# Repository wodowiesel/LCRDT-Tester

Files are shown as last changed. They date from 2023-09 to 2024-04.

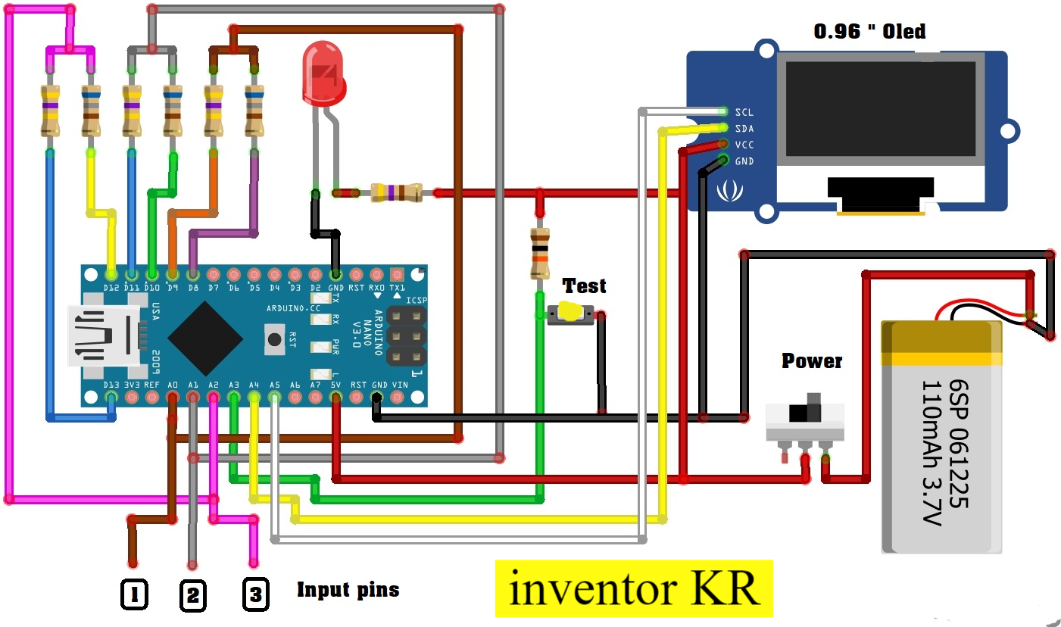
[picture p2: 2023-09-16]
docs/electronic-component-tester-nano.png

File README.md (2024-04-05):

# LCRDT-Tester

The Tester is a tool for identification of the electronic components and its values based on Arduino Nano v3 with internal reference incl. pcb schematics & code.

PCB

Compatibility list:

- Inductors
- Capacitors
- Resistors
- Diodes
- Transistors

- Vloss
- ESR
- Type (PNP/NPN/FET/MOS)
- hFE B

## DISCLAIMERS

**This is still "work-in-progress (WIP)" so I do NOT take any kind of responsibility for damages/data losses!**

**You can use this at your own risk without guarantees and put device on non conductive surface or enclosure!**

If you like the new design yo are free to share it!

Have fun :)

## HARDWARE

- 1x Arduino Nano v3 (or Uno for old versions) + USB-Cable
- 1x Custom PCB for Arduino Nano v3 by WodoWiesel
- 3x 10 kOhm Resistors
- 3x 330 Ohm Resistors
- 1x 100 nF capacitor (or without, just bridge it)
- 1x 4-pin display for +3.3V (0.96" OLED)
- 2x Push-Button (reset & start)
- 1x 3-Pin Male Pin Header (for component testing)
- 1x 4-Pin Male Pin Header (for display)

- 1x Soldering iron
- Solder + flux + IPA

## SOFTWARE

Download my adapted [code](/code-aduino/LCRDT-Tester-WodoWiesel.ino) and configure your setup and load it via Arduino IDE.

## HOW TO USE

1. configure code adapted to your setup regarding used parts and display type

2. upload code to your arduino

3. solder the new pcb

4. put component of choice in the testing headers and read values

## CREDITS

:copyright: 10/10/2023 WodoWiesel

Github (https://github.com/wodowiesel/)

Twitch (https://www.twitch.com/wodowiesel/)

Instagram (https://www.instagram.com/wodowiesel/)

YT (https://www.youtube.com/@wodowiesel/)

E-Mail (wodowiesel@quantentunnel.de)

The new design was checked by the electrical engineer theBrutzler

(https://github.com/theBrutzler/ & https://www.twitch.com/theBrutzler/)

The new optimized PCB was designed with free KiCAD software (https://www.kicad.org/)

:heavy_exclamation_mark: The PCB should be produced at a manufacturer

(like PCBWay or similar) with the RoHS lead-free option for environmental protection.

Originals:

Proekty (https://arduino.ru/forum/proekty/transistor-tester-arduino/)

Vlad (https://github.com/vlad-gheorghe/ardutester/)

Code: Karl-Heinz Kubbeler (version 1.08k, 2013 / 1.10, 2014)

engl. Journal [PDF](/docs/ttester_eng108k.pdf)

## LICENSES

- Hardware

CERN Open Hardware License Version 2 - Weakly Reciprocal

Short identifier CERN-OHL-W-2.0

[LICENSE Source](https://spdx.org/licenses/CERN-OHL-W-2.0.html)

- Software

This work is licensed under a Creative Commons Attribution-NonCommercial 3.0 Unported License.

[CCANC](http://creativecommons.org/licenses/by-nc/3.0/)

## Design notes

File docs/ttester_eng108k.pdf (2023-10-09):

# TransistorTester with AVR microcontroller and a little more Version 1.08k

### Karl-Heinz K¨ubbeler

kh kuebbeler@web.de

### September 25, 2013

# Contents

1 Features | 4
2 Hardware | 7
3 Instructions for use | 15
4 Configuring the TransistorTester | 19
5 Description of the measurement procedures | 24

5.5 Selftest Function | 66
5.5.1 | Some Results of the Selftest Function | 70
6 Known errors and unsolved problems | 73
7 Special Software Parts | 74
8 To Do List and new ideas | 75

## Preface

### Basically Motive

Every hobbyist knows the following problem: You disassemle a Transistor out of a printed board or you get one out of a collection box. If you find out the identification number and you already have a data sheet or you can get the documents about this part, everything is well. But if you don’t find any documents, you have no idea, what kind of part this can be. With conventional approach of measurement it is difficult and time-consuming to find out the type of the part and parameters. It could be a NPN, PNP, N- or P-Channel-Mosfet etc. It was the idea of Markus F. to hand over the work to a AVR microcontroller.

### As my work has started

My work with the software of the TransistorTester of Markus F. [1] has started, because I had problems with my programmer. I had bought a printed board and components, but I could not program the EEprom of the ATmega8 with the Windows driver without error messages. Therefore I took the software of Markus F. and changed all the accesses from the EEprom memory to flash memory accesses. By analysing the software in order to save memory at other places of program, I had the idea, to change the result of the ReadADC function from ADC units to millivolt (mV) units. The mV resolution is needed for any output of voltage values. If ReadADC returns directly the mV resolution, I can save the conversion for each output value. This mV resolution can be get, if you first accumulate the results of 22 ADC readings. The sum must be multiplied with two and divided by nine. Then we have a maximum value of 1023·22·2
9 = 5001, which matches perfect to the wanted mV resolution of measured voltage values. So I additionally had the hope, that the enhancement of ADC resolution by oversampling could help to improve the voltage reading of the ADC, as described in AVR121 [5]. The original version ReadADC has accumulated the result of 20 ADC measurements and divides afterwards by 20, so the result is equal to original ADC resolution. By this way never a enhancement of ADC resolution can take place. So I had to do little work to change the ReadADC, but this forced analysing the whole program and change of all “if-statements” in the program, where voltage values are queried. But this was only the beginning of my work!

More and more ideas to make measurement faster and more accurate has been implemented. Additionally the range of resistor and capacity measurements are extended. The output format for LCD-Display was changed, so symbols are taken for diodes, resistors and capacitors instead of text. For further details take a look to the actual feature list chapter 1. Planned work and new ideas are accumulated in the To Do List in chapter 8. By the way, now I can program the EEprom of the ATmega with Linux operating system without errors.
At this place I would like to thank the originator and software author Markus Frejek, who has enabled the continuation with his initial work. In addition I would like to say thanks to the authors of numerous input to the discussion forum, which have assist me, to find new tasks, weak points and errors. Next I would like to thank Markus Reschke, who give me the permission, to publish his cheerful software versions at the SVN server. Furthermore some ideas and software part of Markus
R. was integrated in my own software version, again thank you very much. I have to thank also Asco B., who has developed a new printed board, to enable the reproductions for other hobbyists. Another thank I would like to send to Dirk W. , who has handled the omnibus order for this printed board. Never I had time anough to handle these things concurrently with my software developement, at no time the state of further developement of software would have the same level. Thanks for the many suggestions to improve the tester to the members of the local chapter of the ”Deutscher Amateur Radio Club (DARC)” in Lennestadt.

# Chapter 1

# Features

1. Operates with ATmega8, ATmega168 or ATmega328 microcontrollers.
2. Displaying the results to a 2x16 character LCD-Display.
3. One key operation with automatic power shutdown.
4. Battery operation is possible since shutdown current is only about 20nA.
5. Low cost version is feasible without crystal and auto power off. With software version 1.05k the sleep modus of the Atmega168 or ATmega328 is used to reduce current if no measurement is required.
6. Automatic detection of NPN and PNP bipolar transistors, N- and P-Channel MOSFETs, JFETs, diodes, double diodes, Thyristors and Triacs.
7. Automatic detection of pin layout of the detected part.
8. Measuring of current amplification factor and Base-Emitter threshold voltage of bipolar transistors.
9. Darlington transistors can be identified by the threshold voltage and high current amplification factor.
10. Detection of the protection diode of bipolar transistors and MOSFETs.
11. Measuring of the Gate threshold voltage and Gate capacity value of MOSFETs.
12. Up to two Resistors are measured and shown with symbols | and values with up to four
decimal digits in the right dimension. All symbols are surrounded by the probe numbers of the Tester (1-3). So Potentiometer can also be measured. If the Potentiometer is adjusted to one of its ends, the Tester cannot differ the middle pin and the end pin.
13. Resolution of resistor measurement is now up to 0.01Ω, values up to 50MΩ are detected.
14. One capacitor can be detected and measured. It is shown with symbol and value with up to four decimal digits in the right dimension. The value can be from 25pF (8MHz clock, 50pF @1MHz clock) to 100mF. The resolution can be up to 1 pF (@8MHz clock].
15. For capacitors with a capacity value above 0.18µF the Equivalent Serial Resistance (ESR) is measured with a resolution of 0.01Ω and shown with two significant decimal digits. This feature is only avaiable for ATmega with at least 16K flash memory (ATmega168 or ATmega328).

16. For capacitors with a capacity value above 5000pF the voltage loss after a load pulse can be determined. The voltage loss give a hint for the quality factor of the capacitor.
17. Up to two diodes are shown with symbol | or symbol | in correct order. Additionally
the flux voltages are shown.
18. LED is detected as diode, the flux voltage is much higher than normal. Two-in-one LEDs are also detected as two diodes.
19. Zener-Diodes can be detected, if reverse break down Voltage is below 4.5V. These are shown as two diodes, you can identify this part only by the voltages. The outer probe numbers, which surround the diode symbols, are identical in this case. You can identify the real Anode of the diode only by the one with break down (threshold) Voltage nearby 700mV!
20. If more than 3 diode type parts are detected, the number of founded diodes is shown additionally to the fail message. This can only happen, if Diodes are attached to all three probes and at least one is a Z-Diode. In this case you should only connect two probes and start measurement again, one after the other.
21. Measurement of the capacity value of a single diode in reverse direction. Bipolar Transistors can also be analysed, if you connect the Base and only one of Collector or Emitter.
22. Only one measurement is needed to find out the connections of a bridge rectifier.
23. Capacitors with value below 25pF are usually not detectet, but can be measured together with a parallel diode or a parallel capacitor with at least 25pF. In this case you must subtract the capacity value of the parallel connected part.
24. For resistors below 2100Ω also the measurement of inductance will be done, if your ATmega has at least 16K flash memory. The range will be from about 0.01mH to more than 20H, but the accuracy is not good. The measurement result is only shown with a single component connected.
25. Testing time is about two seconds, only capacity or inductance measurement can cause longer period.
26. Software can be configured to enable series of measurements before power will be shut down.
27. Build in selftest function with optional 50Hz Frequency generator to check the accuracy of clock frequency and wait calls (ATmega168 and ATmega328 only).
28. Selectable facility to calibrate the internal port resistance of port output and the zero offset of capacity measurement with the selftest (ATmega168 and ATmega328 only). A external capacitor with a value between 100nF and 20µF connected to pin 1 and pin 3 is necessary to compensate the offset voltage of the analog comparator. This can reduce measurement errors of capacitors of up to 40µF. With the same capacitor a correction voltage to the internal reference voltage is found to adjust the gain for ADC measuring with the internal reference.

Thyristors and Triacs can only be detected, if the test current is above the holding current. Some Thyristors and Triacs need as higher gate trigger current, than this Tester can deliver. The available testing current is only about 6mA! Notice that all features can only be used with microcontroller with more program memory such as ATmega168.

Attention: Allways be shure to discharge capacitors before connecting them to the Tester! The Tester may be damaged before you have switched it on. There is only a little protection at the ATmega ports.
Extra causion is required if you try to test components mounted in a circuit. In either case the equipment should be disconnected from power source and you should be shure, that no residual voltage remains in the equipment.

# Chapter 2

# Hardware

## 2.1 Circuit of the TransistorTester

The circuit of the TransistorTester in figure 2.1 is based on the circuit of Markus F. released in Abb. 1 of AVR-Transistortester report [1]. Changed or moved parts are marked with green color, optional parts are marked with red color.
Some changes are made because the electronical power switch make problems in some implemen-tations. Therefore the resistor R7 is reduced to 3.3kΩ. The capacitor C2 is reduced to 10nF and R8 is moved so that the PD6 output does not try to switch the C2 capacitor directly. Additional blocking capacitors are added and should be placed near the power connection of the Atmega and near the Voltage regulator.
Because the PD7 input and PC6 (RESET) are the only pins, where pull up resistors where needed, one extra 27kΩ resistor is added to the PD7 (pin 13) input. With this modification the software can disable all internal pull up resistors of the ATmega.
The additional crystal with its 22pF capacitors are optional added. The accuracy of a crystal has the benefit of more stable time measurement for getting the capacitor values.
New software version can use a voltage scale switch of the ADC. The speed of switching is reduced by the external capacitor C1 at the AREF (21) pin of the ATmega. To avoid slowing down the measurement speed more than necessary, the value of this capacitor should be reduced to 1nF. Removing of the capacitor C1 is also possible. For adapting the software to the actual circuit take a look to the Makefile options in the configuring chapter 4.
Some different versions of R11 / R12 resistor combinations circulates in the internet. I have adapted my software to the original of Markus F. [1] with 10kΩ and 3.3kΩ.
The additional 2.5V precision voltage reference connected at pin PC4 (ADC4) can be used to check and calibrate the VCC voltage, but is not required. You can use a LM4040-AIZ2.5 (0.1%), a LT1004CZ-2.5 (0.8%) or a LM336-Z2.5 (0.8%) as voltage reference. A optional ISP connector has been added to easier load new software versions to the tester.

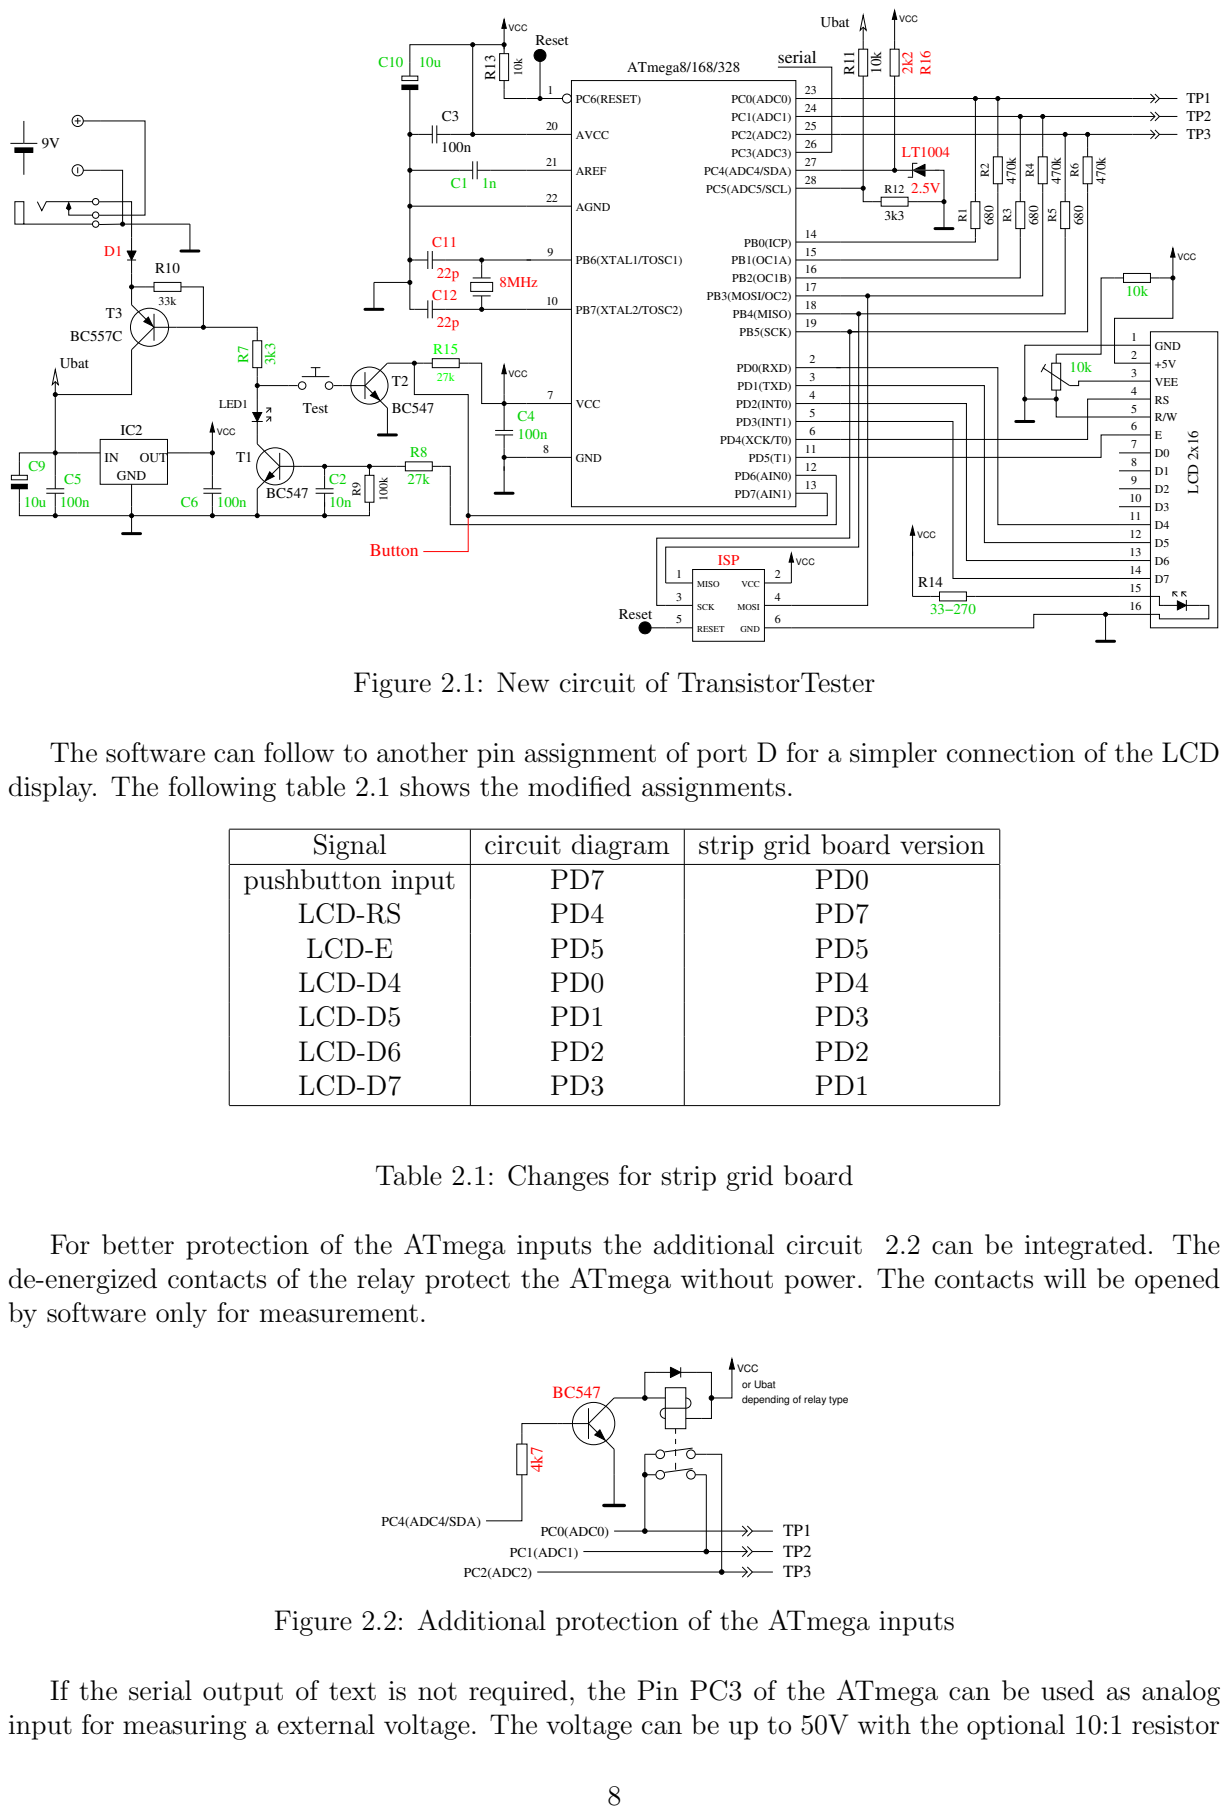
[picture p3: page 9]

Figure 2.1: New circuit of TransistorTester

The software can follow to another pin assignment of port D for a simpler connection of the LCD
display. The following table 2.1 shows the modified assignments.

Signal | circuit diagram | strip grid board version
pushbutton input LCD-RS LCD-E LCD-D4 LCD-D5 LCD-D6 LCD-D7 | PD7 PD4 PD5 PD0 PD1 PD2 PD3 | PD0 PD7 PD5 PD4 PD3 PD2 PD1

Table 2.1: Changes for strip grid board

For better protection of the ATmega inputs the additional circuit 2.2 can be integrated. The
de-energized contacts of the relay protect the ATmega without power. The contacts will be opened
by software only for measurement.

VCC Figure 2.2: Additional protection of the ATmega inputs

or Ubat
depending of relay type

If the serial output of text is not required, the Pin PC3 of the ATmega can be used as analog
input for measuring a external voltage. The voltage can be up to 50V with the optional 10:1 resistor

divider and can be used for measuring the breakdown voltage of a zener diode. A current limiting power supply with up to 50V can be switched on with low signal at PD7 pin of the ATmega to deliver current for testing the break down voltage of a zener diode. Figure 2.3 shows a suggestion for this expansion. The tester shows the external voltage as long as you hold the key pressed. About 40mA more battery current is used by this expansion during key pressing.

Vin+

Vin−

Com DC−DC Conv.

Vout+15

Vout−15

R18

180k

R17

20k

10n

serial / PC3

External
Voltage

1uF

33uH

L1

C13

Uext
10k

TMA0515D

T4
Uext

Button

R19

Ubat

C15

100n

Can be placed on Tester board! Should be placed separate!

IN OUT

IC3

GND

MCP1702

IRFU9024

C17

C16

50u 100n
C14

Figure 2.3: Expansion for measuring of break down voltage of Zener diodes

## 2.2 Hints for building the TransistorTester

Every LCD-display with at least 2x16 character and a HD44780 compatible controller can be used with the TransistorTester. You should respect the current needed for illumination, some LCD need lower current than others. I had tried OLED type displays, but this type cause interference with measurements of the ATmega and are not recommended. Also loading of special characters for displaying the resistor symbol has caused problems with the OLED.
The resistors R1 to R6 are critical for measurements and this 680Ω and 470kΩ resistors should be measurement type resistors (tolerance of 0.1%) to get the full accuracy. You should use a precision socket for the ATmega microcontroller to enable the replacement of the microcontroller. The microcontroller ATmega8, ATmega168 and ATmega328 can be used. Recommended is a ATmega168 or ATmega328, if you wish to use all features.
Anyway you should assemble all parts to printed board without the microcontroller. A up-to-date low voltage drop regulator like MCP1702-5002 is recommended as IC2, because it need only 2µA of standby current and can still deliver 5V, if your input voltage is only 5.4V. But this part is not pin compatible to well known 78L05 with TO92 body!
After checking, that all needed parts are at the correct place, you should first connect the battery or power supply to the printed board without LCD-display and microcontroller. You should check the voltage at the power pins of the microcontroller and LCD-display terminal during the Test key is pressed. The voltage should disappear, if you release the Test key. If the voltage had correct polarity and value, you should disconnect the power and assemble the microcontroller with correct alignment. Be careful and make shure, that all pins of the microcontroller are in the socket holes. Now you can also connect the LCD. Check if power pins of the LCD has the right connection to GND and VCC of your board.
If you are shure that everything is all right, reconnect the power. If you have already programmed the ATmega, you can press the Test button. By pressing the Test key, the background light of the LCD should switch on. If you release the Test button, the LED should illuminate weak. Notice, that the software for the microcontroller must be compiled for the correct processor type. A program for the ATmega8 does not run on a ATmega168!

2.3 Changeover for tester versions designed by Markus F.

Voltage control If the problem exist, the tester will shut down immediately with every switch on. With imy suggested setting of the fuses (Makefile) the voltage control of the different ATmega versions is switched to 4V (brown out level). This may be the reason why the tester makes trouble with the power on sequence. The Pin PD6 tries to switch the 100nF capacitor C2 to VCC level causing a voltage breakdown of the VCC voltage (5V). The capacitor C2 can be reduced to <10nF without problems. If possible, the direct connection of PD6 should be replaced by a resistor >220Ω.

Improvement of power on circuit Often this problem is the reason, if the tester starts with the button hold pressed, but switch off directly by releasing. The problem is enforced by a high current background light for the LCD. The resistor R7 to the base of the PNP transistor T3 was optimized with the value 27kΩ too much to save power consuming. To improve the switching with lower battery voltage or lower current amplification factor of the PNP transistor T3, you should reduce the resistance to 3.3kΩ.

Additional pull-up resistor at PD7 The missing pull-up resistor results to a switch off of the tester with the message ”Timeout” after a short display time. The software is configured with the option PULLUP DISABLE, that all internal pull-up resistors are switched off. For that reason the voltage of pin PD7 is not definded, if the level is not switched by the push button or transistor T2 to GND. One external pull-up resistor of 27kΩ to VCC avoid this error.

Capacitor C1 at the AREF pin Many designs use a 100nF capacitor at the AREF pin, like the design of Markus F. too. As long as the reference voltage of the ADC is never changed, this is a good solution. The software of the TransistorTester for the ATmega168/328 uses a automatic selection of the internal 1.1 V reference voltage of the ADC, if the input voltage is below 1V. With this solution a better resolution of the ADC can be reached for little input voltages. Unfortunately the switching from 5V to 1.1V reference is very slowly. A additional wait time of 10ms must be respected for this reason. With changing the capacity value to 1nF this wait time can be reduced significant. I have not noticed any degration of measurement quality with this change. Even a removing of the capacitor has no significant change of measurement results. If you prefer to leve the capacitor unchanged, you can remove the option NO AREF CAP in the Makefile to activate longer wait times in the program.

Expanding of a 8MHz crystal With some skill you can expand a 8MHz crystal to the backside of the printed board directly to the pins PB6 and PB7 (pin 9 and pin 10). My own expansion was done without the both 22pF capacitors. This solution has operated well with all tested ATmega. But it is not required to use a crystal. You can still use the 8MHz RC oszillator by setting the fuses to get the better resolution of time constant measuring (capacity value).

Smoothing of the operating voltage The original circuit of Markus F. shows only one 100nF capacitor to block the VCC voltage. This is clearly too little smoothing. You should at least use one 100nF near the ATmega power pins and one near the voltage regulator. The input of the voltage regulator should be blocked with a 100nF too. Additional 10µF capacitors (electrolytic or ceramic) at the input and output of the voltage regulator can stable the voltage level. Ceramic 10µF capacitos with SMD mounting form are easier to use for backfitting and have usually a lower ESR value.

Selection of the ATmega processor The using of the base function of the tester is still possible with a ATmega8. The flash memory of that device is used near 100% . Because the ATmega168 or ATmeg328 processors are pin-compatible to the ATmega8, I can recommend the replacement. Actually the price for ATmega328 is so cheap, that there is no reason to take a ATmega168 type. With a ATmega168/328 you get the following advantages: Self test with automatic calibration.
Improvement of measurement quality by automatic switching of ADC scale.

Measurement of inductors with resistance below 2100Ω. Measurement of ESR value of capacitors with value of above 0.18µF. The resolution of resistor measurement below 10Ω is 0.01Ω.
Using of pin PC4 as serial output.

Missing precision voltage reference Usually the software should detect the missing voltage reference with the unconnected pin PC4. In this case no VCC=x.xV message should appear in row 2 of the LCD on power on. If this message appear without the reference, you should connect a 2.2kΩ resistor to the PC4 input and VCC.

## 2.4 Chinese clones

As I know, the tester is rebuild in China in two versions. The first model is rebuild from the first design of Markus F. without the ISP port. The assembled ATmega8 is placed in a socket, so you can replace it with a ATmega168 or ATmega328. For this version you should consider all the hints of section 2.3. Additional 100nF ceramic cpacitors should be connected near by the VCC-GND and AVCC-GND pins of the ATmega for better stabilization of the power voltage. In addition you should notice, that if you expand the board with the additional 8 MHz crystal, your external ISP programmer must have a external clock for programming.

The second version of rebuilded tester is build with SMD components. Also the fix installed ATmega168 is a SMD type with 32TQFP body. Fortunately on the board is a 10-pole ISP connector provided for the programming. I have analysed the board version ”2.1 2012/11/06”. One error is the assembly of the part ”D1”, which should be a precision 2.5V voltage reference. Assembled is only a zener diode. This part should be removed. You can mount a LM4040AIZ2.5 or LT1004CZ-2.5 precision voltage reference at this place. A missing voltage reference is noticed by the software, so that you must not install the voltage reference. My exemplar was delivered with software version 1.02k. The 10-pole ISP plug was not assembled and I must install a jumper from ISP pin 6 to ISP pin
10. My programmer expect a GND connection at pin 10, but the board has GND level only on pin 4 and pin 6 of the ISP. The label of the ATmega168 was rub away and there was no documentation delivered with the part. The lock fuses of the ATmega were set, so no readout was possible. But I could install the software version 1.05k without any problems. Another user has problems with the same software version 1.05k. This user has the chinese board ”2.2 2012/11/26”. The software runs only without problems, if a additional 100nF keramic capacitor was placed between the pin 18-AVCC and 21-GND near by the ATmega. The software 1.05k uses the sleep state of the ATmega for waiting time. For this reason the current alternates often and the voltage regulator is stressed more. Further I have noticed, that the VCC voltage is blocked with a 100nF ceramic capacitor and with a 220µF electrolytic capacitor nearby the 78L05 voltage regulator. The 9V supply voltage is blocked with the same capacitors, but not at the input of the regulator but at the emitter of the PNP transistor (parallel with the battery). The printed circuit board track from the ATmega168 to the test port is very thin, so that a resistance of 100mΩ could be measured for one path. This will be the reason for measuring a resistance of 0.3Ω for two direct connected pins. The ESR measuring can usually consider this by zero compensation. Beginning with version 1.07k the software does respect this offset for measuring resistors below 10Ω too.

## 2.5 Programming of the microcontroller

I release the software for the microcontroller with source code. The developement is done with Linux operationg system (Ubuntu) and is controlled with a Makefile. The Makefile makes shure, that your software will be compiled with the prior selected Makefile options. Some constellations are precom-piled with the source. Please take a look to the ReadMe.txt file in the directory Software/default and to the chapter 4. The result of compilation have the extensions .hex and .eep . Usually the names will be TransistorTester.hex and TransistorTester.eep . The .hex file contains the data for the program memory (flash) of the ATmega processor. The .eep file contains the data for the EEprom memory of the ATmega. Both data files must be loaded to the correct memory.
Additionally the operating state of the ATmega processor must be programmed with the “fuses”. If you can use my Makefile and additionally the program avrdude [12], you need no exact knowledge of the details about the fuses. You have only to type “make fuses” if you have no crystal or “make fuses-crystal” if you have installed the 8MHz crystal to your printed board. With the ATmega168 series of the microcontroller you can also use “make fuses-crystal-lp” to use a crytal with the low power mode. Never choose the crystal mode of clock generation, if you don’t have installed the 8MHz crystal. If you are not shure with the fuses, leave them as default set by manufactor and first bring the the tester to operation in this mode. Maybe your program runs too slow, if you use program data compiled for 8MHz operation, but you can correct this later! But a wrong set of fuses may inhibit later ISP-programming. If you use the Windows operating system, the easiest way to get a correct programmed ATmega is to use the WinAVR package [16],[17]. With my patch [18] you can also set the fuses by using the Makefile. Of course the avrdude program must support your programmer and the configuration in the Makefile must match to your environment.
The figures 2.4 show the File menu of the graphical user interface of WinAVR for open the file Makefile and for saving the changed Makefile (Save).

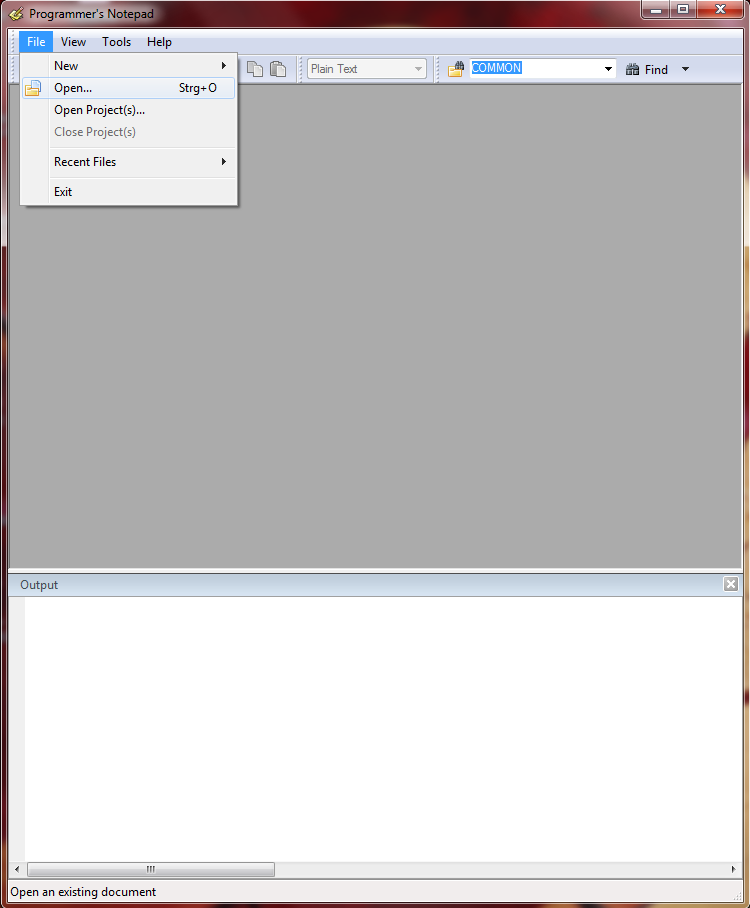
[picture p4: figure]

(a) open Makefile | (b) save Makefile

Figure 2.4: Using of the WinAVR user interface Programmer’s Notepad

The next figures 2.5 show the Tools menu of the Programmer’s Notepad for compiling the program (Make All) and for programming the ATmega (Program) with avrdude.

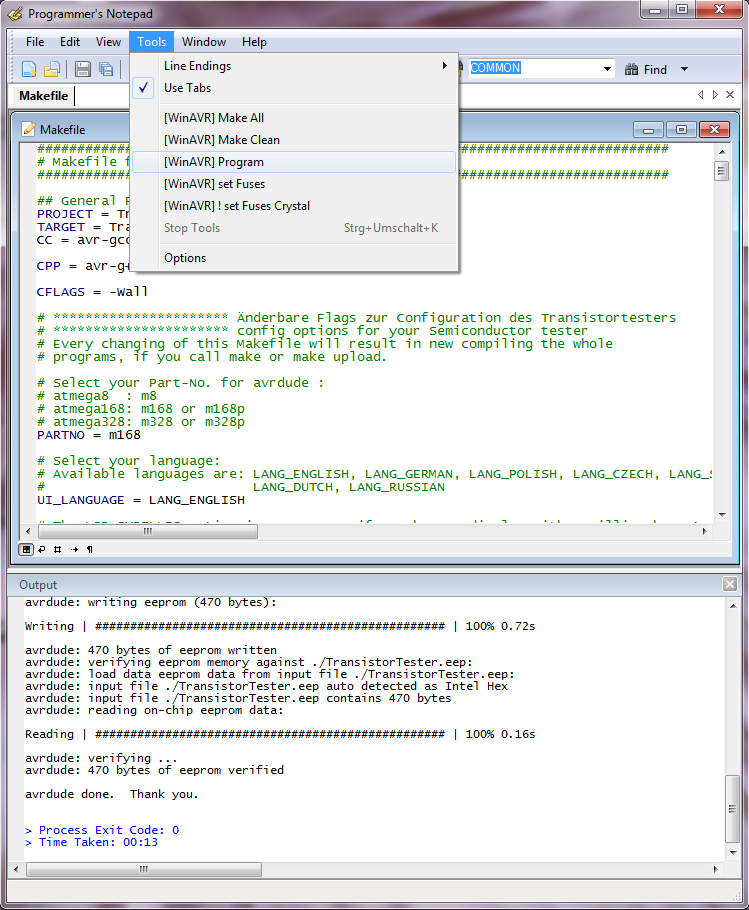
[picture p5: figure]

(a) Build programming data (.hex/.eep) | (b) Programming the ATmega

Figure 2.5: Using of the WinAVR user interface Programmer’s Notepad

## 2.6 Troubleshooting

In most cases of problems you will miss the text output to the LCD-display. At first you should check, if the LED was illuminated weak, if you release the Test button.

Power does not switch on. If the LED is without light and the VCC power has correct 5V voltage during holding the Test button, the microcontroller does not switch the power correctly. The microcontroller should hold the power by switching the PD6 output to 5V, which is usually done as one of the first actions. If you hold the Test key pressed, the power is switched on anyway. So you can check the value of VCC power and additionally the voltage value of the PD6 output, if you hold the key pressed. If VCC voltage has correct value (5V), but PD6 voltage is below 4V, your microcontroller does not start the program. In this case you should check if the microcontroller flash has been loaded with proper data for your installed type and if ATmega is correctly configured with the fuses. If your ATmega put the PD6 output to 5V and the power does not stay if you release the Test key, it is more difficult to find the reason. First you can shorten the LED and try again. If your Tester now starts, your LED may be faulty or mounted with wrong polarity. If this is not the reason, the current amplification factor of your T3 transistor (BC557C) is insufficient. The current to the base of T3 is lower in the microcontroller state as in the “key pressed” state.

Nothing is readable on the LCD display Check the voltage at the contrast pin at the LCD display (pin 3). Adjust to correct value specified in the data sheet of your display and optimize by viewing. If you have a high temperature display type, you must provide a negative contrast voltage for operation. In this case you can use the ICL 7660 device for generating a negative voltage from positive 5V.

If there is no output readable on the LCD and the background light is on, you should disconnect the power and check all four data plus the two control signal connections. If all connection are well, the only reason I see is a uncorrect timing of control signals. This can be caused by a slower LCD controller than expected by the software or the ATmega software runs at wrong clock speed. Please check for which clock speed your programming data was compiled and if the fuses of the ATmega are correct set to that speed. You find the clock parameter in the corresponding Makefile. If the tester is build without the switch off electronic, you can test with a LED connected to the test pins, if the program operates normally. If the LED flickers, the program operates well. The missing text on the LCD must be caused by wrong connection or timing.

Something but not all is readable on the LCD display Check if the .eep data are loaded to the EEprom memory of ATmega. If all data are loaded correctly, you should check the clock speed of your programming data (Makefile) and ATmega processor settings (fuses).

Measurement is slow and Capacitors are measured about 8 times too small You run software compiled for 8MHz clock at real clock speed of 1MHz. Please set the fuses of the ATmega correctly.

Measurement has strangely values Check if your programmer is still connected to the ISP-plug. The ISP interface should be disconnected for measuring. Very often the reason of wrong measurements is the use of software compiled with the AUTOSCALE ADC option and with the option NO REF CAP, but the capacitor at the AREF pin has still a value of 100nF. Wrong assembly of components or remaining soft solder flux can disturb the measurements too. Please check with the selftest function of your TransistorTester software if possible. For the details see Chapter 5.5.

Otherwise inspect your board visually and check the resistor values with a ohmmeter. You can use the pins of the ATmega for this check, for example to check the R1 you can measure between pin 23 and pin 14. Take a look at the circuit diagram 2.1 for details. There is no need to remove the microcontroller, only battery or power supply should be removed before.

The Tester switch off the power after 2 seconds display time This condition exists, if the external Pull-Up resistor at the PD7 input is missing or the key button is keep pressed. The software switch off the internal Pull-Up resistors to prevent a influence to the measurement results. Therefore a external Pull-Up resistor (27k) is required.

# Chapter 3

# Instructions for use

## 3.1 The measurement operation

Using of the Transistor-Tester is simple. Anyway some hints are required. In most cases are wires with alligator clips connected to the test ports with plugs. Also sockets for transistors can be connected. In either case you can connect parts with three pins to the three test ports in any order. If your part has only two pins, you can connect this pins to any two of the tree test ports. Normally the polarity of part is irrelevant, you can also connect pins of electrolytical capacitors in any order. The measurement of capacity is normally done in a way, that the minus pole is at the test port with the lower number. But, because the measurment voltage is only between 0.3 V and at most 1.3 V, the polarity doesn´t matter. When the part is connected, you should not touch it during the measurement. You should put it down to a nonconducting pad if it is not placed in a socket. You should also not touch to the isolation of wires connected with the test ports, the measurement results can be affected. Then you should press the start button. After displaying a start message, the measurement result should appear after two seconds. If capacitors are measured, the time to result can be longer corresponding to the capacity.
How the transistor-tester continues, depends on the configuration of the software.

Single measurement mode If the tester is configured for single measurement mode, the tester shut off automatical after displaying the result for 10 seconds for a longer lifetime of battery. During the display time a next measurement can be started by pressing the start button. After the shut off a next measurement can be started too of course. The next measurement can be done with the same or another part. If you have not installed the electronic for automatic shut down, your last measurement result will be displayed until you start the next measurement.

Endless measurement mode A special case is the configuration without automatical shut off. This configuration is normally only used without the transistors for the shut off function. A external off switch is necessary for this case. The tester will repeat measurements until power is switched off.

Multi measurement mode In this mode the tester will shut down not after the first measurement but after a configurable series of measurements. In the standard case the tester will shut down after five measurements without found part. If any part is identified by test, the tester is shut down after double of five (ten) measurements. A single measurement with unknown part after a series of measurement of known parts will reset the counter of known measuerements to zero. Also a single measurement of known part will reset the counter of unknown measurements to zero. This behavior can result in a nearly endless series of measurements without pressing the start button, if parts are disconnected and connected in periodical manner.

In this mode there is a special feature for the display period. If the start button is pressed only short for switching on the tester, the result of measurement ist only shown for 5 seconds. Buf if you press and hold the start button until the first message is shown, the further measurement results are shown for 14 seconds. The next measurement can started earlier by pressing the start button during the displaying of result.

## 3.2 Selftest and Calibration

If the software is configured with the selftest function, the selftest can be started by connecting all three test ports together and pushing of the start button. In this case all of the documented tests in the Selftest chapter 5.5 will be done. The repetition of the tests can be avoided, if the start button is hold pressed. So you can skip uninteresting tests fast and you can watch interresting tests by releasing the start button. The test 4 will finish only automatically if you separate the test ports (release connection).
If the function AUTO CAL is selected in the Makefile, the zero offset for the capacity measurement will be calibrated with the selftest. It is important for the calibration task, that the connection between the three test ports is relased during test number 4. You should not touch to any of the test ports or connected cables when calibration (after test 6) is done. But the equipment should be the same used for further measurements. Otherwise the zero offset for capacity measurement is not detected correctly. The resistance values of port outputs are determined at the beginning of every measurement with this option.
A capacitor with any capacity between 100nF and 20µF connected to pin 1 and pin 3 is required for the last task of calibration. To indicate that, a capacitor symbol is shown between the pin number 1 and 3, followed by the text ” >100nF”. You should connect the capacitor not before this text is shown. With this capacitor the offset voltage of the analog comparator will be compensated for better measurement of capacity values. Additionally the gain for ADC measurements using the internal reference voltage will be adjusted too with the same capacitor for better resistor measurement results with the AUTOSCALE ADC option.
The zero offset for the ESR measurement will be preset with the option ESR ZERO in the Makefile. With every self test the ESR zero values for all three pin combinations are determined. The solution for the ESR measurement is also used to get the values of resistors below 10Ω with a resolution of 0.01Ω.

## 3.3 special using hints

Normally the Tester shows the battery voltage with every start. If the voltage fall below a limit, a warning is shown behind the battery voltage. If you use a rechargeable 9V battery, you should replace the battery as soon as possible or you should recharge. If you use a tester with attached 2.5V precision reference, the measured supply voltage will be shown in display row two for 1 second with ”VCC=x.xxV”.
It can not repeat often enough, that capacitors should be discharged before measuring. Otherwise the Tester can be damaged before the start button is pressed. If you try to measure components in assembled condition, the equipment should be allways disconnected from power source. Furthermore you should be shure, that no residual voltage reside in the equipment. Every electronical equipment has capacitors inside!
If you try to measure little resistor values, you should keep the resistance of plug connectors and cables in mind. The quality and condition of plug connectors are important, also the resistance of cables used for measurement. The same is in force for the ESR measurement of capacitors. With poor connection cable a ESR value of 0.02Ω can grow to 0.61Ω.

You should not expect very good accuracy of measurement results, especially the ESR measurement and the results of inductance measurement are not very exact. You can find the results of my test series in chapter 5.

## 3.4 Compoments with problems

You should keep in mind by interpreting the measurement results, that the circuit of the TransistorTester is designed for small signal semiconductors. In normal measurement condition the measurement current can only reach about 6 mA. Power semiconductors often make trouble by reason of residual current with the identification an the measurement of junction capacity value. The Tester often can not deliver enough ignition current or holding current for power Thyristors or Triacs. So a Thyristor can be detected as NPN transistor or diode. Also it is possible, that a Thyristor or Triac is detected as unknown.
Another problem is the identification of semiconductors with integrated resistors. So the base -emitter diode of a BU508D transistor can not be detected by reason of the parallel connected internal 42Ω resistor. Therefore the transistor function can not be tested also. Problem with detection is also given with power Darlington transistors. We can find often internal base - emitter resistors, which make it difficult to identify the component with the undersized measurement current.

## 3.5 Measurement of PNP and NPN transistors

For normal measurement the three pins of the transistor will be connectet in any order to the measurement inputs of the TransistorTester. After pushing the start button, the Tester shows in row 1 the type (NPN or PNP), a possible integrated protecting diode of the Collector - Emitter path and the sequence of pins. The diode symbol is shown with correct polarity. Row 2 shows the current amplification factor (B=...) and the Base - Emitter threshold voltage. You shouls know, that the Tester can measure the amplification factor with two different circuits, the common Emitter and the common Collector circuit (Emitter follower).
With the common Emitter circuit the tester has only two alternative to select the base current:
1. The 680Ω resistor results to a base current of about 6.1mA. This is too high for low level transistors with high amplification factor, because the base is saturated. Because the collector current is also measured with a 680Ω resistor, the collector current can not reach the with the amplification factor higher value. The software version of Markus F. has measured the Base -Emitter threshold voltage in this ciruit (Uf=...).
2. The 470kΩ resistor results to a base current of only 9.2µA . This is very low for a power transistor with low current amplification factor. The software version of Markus F. has identified the current amplification factor with this circuit (hFE=...).

The software of the Tester figure out the current amplification factor additionally with the common Collector circuit. The higher value of both measurement methodes is reported. The common collector circuit has the advantage, that the base current is reduced by negative current feedback corresponding to the amplification factor. In most cases a better measurement current can be reached with this methode for power transistors with the 680Ω resistor and for Darlington Transistors with 470kΩ resistor. The reported Base - Emitter threshold voltage Uf is now measured with the same current used for determination of the current amplification factor. However, if you want to know the Base - Emitter threshold voltage with a measurement current of about 6mA, you have to disconnect the Collector and to start a new measurement. With this connection, the Base - Emitter threshold voltage at 6 mA is reported. The capacity value in reverse direction of the diode is also reported. Of course you can also analyse the base - collector diode.

## 3.6 Measurement of JFET and D-MOS transistors

Because the structure of JFET type is symmetrical, the Source and Drain of this transistores can not be differed. Normally one of the parameter of this transistor is the current of the transistor with the Gate at the same level as Source. This current is often higher than the current, which can be reached with the measurement circuit of the TransistorTester with the 680Ω resistor. For this reason the 680Ω resistor is connected to the Source. Thus the Gate get with the growing of current a negative bias voltage. The Tester reports the Source current of this circuit and additionally the bias voltage of the Gate. So various models can be differed. The D-MOS transistors (depletion type) are measured with the same methode.
You should know for enhancement MOS transistors (P-E-MOS or N-E-MOS), that the measurement of the gate threshold voltage (Vth) is more difficult with little gate capacity values. You can get a better voltage value, if you connect a capacitor with a value of some nF parallel to the gate /source. The gate threshold voltage will be find out with a drain current of about 3.5mA for a P-E-MOS and about 4mA for a N-E-MOS.

# Chapter 4

# Configuring the TransistorTester

The complete software for the TransistorTester is available in source code. The compilation of modules is controlled with a Makefile. The developement was done at the Ubuntu Linux operating system with the GNU toolchain (gcc version 4.5.3). It should be possible to use other Linux operating systems without problems. To load the compiled data to the flash memory or the EEprom memory, the tool avrdude (version 5.11svn) was taken by the Makefile, if you call “make upload”. The program avrdude [12] is available for Linux and Windows operating system. The gnu C-compiler gcc is also taken by the AVR studio software and by the WinAVR [16],[17] software at the Windows operating system. You can load the program data (.hex and .eep) also with other tools to the ATmega, but only my Makefile version takes care to load the correct data to the choosed processor. Avrdude loads only data to the ATmega if the Signature Bytes of the connected ATmega is identical to the choosed one. If you alter the Makefile, all the software will be compiled new, if you call a “make” or “make upload” command. The software compiled for a ATmega8 does not run on a ATmega168. The software compiled for a ATmega328 does not run on the ATmega168! A exeption fron this rule is
the software compiled for ATmega168, this data can also be used for a ATmega328 without changes.
Be careful, if you don’t use my Makefile.
With the correct options set, my software runs on the unchanged hardware of Markus F. (PARTNO=M8, NO option NO AREF CAP and NO PULLUP DISABLE option). The clock rate can also be set to
8 MHz with fuses, no crystal is required!
The following options in the Makefile are avaiable to configure the software for your Tester.

PARTNO describes the target processor:
m8 = ATmega8
m168 or m168p = ATmega168
m328 or m328p = ATmega328
example: PARTNO = m168

UI LANGUAGE specifies the favored Language
LANG ENGLISH, LANG GERMAN, LANG POLISH, LANG CZECH, LANG SLOVAK, LANG SLOVENE, LANG DUTCH, LANG BRASIL, LANG RUSSIAN and LANG UKRAINIAN is currently avaiable. The russian or ukrainian language requires a LCD with cyrillic character set.
example: UI LANGUAGE = LANG ENGLISH

LCD CYRILLIC is only needed for a LCD-display with cyrillic character set. The µ and Ω character is not avaiable with the cyrillic character set. If you specify this option, both characters are loaded to the LCD with software.
example: CFLAGS += -DLCD CYRILLIC

LCD DOGM must be set, if a LCD with ST7036 controller (Type DOG-M) is used for displaying. The LCD-contrast is then set with software commands.

example: CFLAGS += -DLCD DOGM

STRIP GRID BOARD This option adapts the software to a changed port D connection for strip grid printed boards. You can find the details in the chapter hardware 2.1.

WITH SELFTEST If you specify this Option, software will include a selftest function. Selftest will be started, if you connect all three probes together and start measurement.
example: CFLAGS += -DWITH SELFTEST

AUTO CAL The zero offset for capacity measurement will be written additionally to the EEprom with the selftest routine. Additionally the offset voltage of the analog comparator (REF C KORR) and the voltage offset of the internal reference voltage (REF R KORR) will be measured automatically, if you connect a capacitor with a capacity value between 100nF and 20µF to pin 1 and pin 3 after measurement of capacity zero offset. All found values will be written to EEprom and will be used for further measurements automatically. The port output resistance values will be determined at the beginning of each measurement.
example: CFLAGS += -DAUTO CAL

FREQUENCY 50HZ At the end of selftest a 50 Hz Signal will be generated on Port 2 and Port 3 for up to one minute.
example: CFLAGS += -DFREQUENCY 50HZ

CAP EMPTY LEVEL This option defines the voltage level for discharged capacitor (mV units). You can set the level to higher value as 3mV, if the tester does not finish discharging of capacitors. In this case the tester ends after longer time with the message “Cell!”.
example: CFLAGS += -DCAP EMPTY LEVEL=3

WITH AUTO REF specifies, that reference voltage is read to get the actual factor for capacity measuring of low capacity values (below 40µF).
example: CFLAGS += -DWITH AUTO REF

REF C KORR specifies a offset for readed reference voltage in mV units. This can be used to adjust the capacity measurement of little capacitors. A correction value of 10 results to about 1 percent lower measurement results. If the option AUTO CAL is selected together with the WITH SELFTEST option, the REF C KORR will be a offset to the measured voltage difference of the test capacitor and the internal reference voltage.
example: CFLAGS += -DREF C KORR=14

REF L KORR specifies a additional offset in mV units to the reference voltage for the measurement of inductance values. The REF C KORR offset and respectively the offset value from the calibration is additionally used with the inductance measurement. The REF L KORR value will be subtracted for measurements without a 680Ω resistor, for measurements with a 680Ω resistor the value will be added.
example: CFLAGS += -DREF L KORR=40

C H KORR specifies a correction value for the measurement of big capacitor values. A value of 10 results to 1 percent lower measurement results.
example: CFLAGS += -DC H KORR=10

WITH UART uses the pin PC3 as output for the serial text (V24). If the option is not set, the pin PC3 can be used for reading a external voltage with a 10:1 resistor divider. With this equipment you can check the breakdown voltage of zener diodes, which have more than 4.5V breakdown voltage. This measurement will repeat with 3 measurements per second until you

release the Start button.
example: CFLAGS += -DWITH UART

AUTOSCALE ADC enables the automatic scale switchover of the ADC to either VCC or internal reference. Internal reference gives a 2.56V scale for ATmega8 and a 1.1V scale for other processors.
example: CFLAGS += -DAUTOSCALE ADC

ESR ZERO defines a zero offset for ESR measurements. The zero offsets for all three pin combinations will be determined with the selftest and replaces the preset zero offset. This zero offsets will be subtracted from all ESR measurements. Example: CFLAGS += -DESR ZERO=29

NO AREF CAP tells your Software, that you have no capacitor (100nF) installed at pin AREF (pin 21). This enables a shorter wait-time for the AUTOSCALE ADC scale switching of the ADC. A 1nF capacitor was tested in this mode without detected errors. Figure 4.1a and 4.1b show the switching time with a 1nF capacitor. As you can see the switching from 5V to 1.1V is much slower than switching back to 5V. If you have still installed the 100nF, switching time will be about factor 100 longer!
example: CFLAGS += -DNO AREF CAP

REF R KORR specifies a offset for the internal ADC-reference voltage in mV units. With this offset a difference by switching from VCC based ADC reference to internal ADC reference for resistor measurement can be adjusted. If you select the AUTO CAL option of the selftest section, this value is only a additionally offset to the found voltage difference in the AUTO CAL function.
example: CFLAGS += -DREF R KORR=10

OP MHZ tells your software at which Clock Frequency in MHz your Tester will operate. The software is tested only for 1 MHz, 8MHz and additionally 16MHz. The 8MHz operation is recommended for better resolution of capacity and inductance measurement.
example: OP MHZ = 8

RESTART DELAY TICS must be set to 6, if the ATmega168 or ATmega328 is used with the internal RC-oszillator instead of the crystal oszillator. If this value is not preset, the software respects the 16384 clock tics delay for restart from sleep mode with the crystal operation. example: CFLAGS += -DRESTART DELAY TICS=6

USE EEPROM specifies if you wish to locate fix text and tables in EEprom Memory. Otherwise the flash memory is used. Recommended is to use the EEprom (option set).
example: CFLAGS += -DUSE EEPROM

EBC STYLE specifies, that the output of transistor pin layout is done with format “EBC=...” or “GDS=...”. This way of output save program memory for the ATmega. Without this option the layout is shown with the format “123=...”, where every point represent a E (Emitter), B (Base) or C (Collector). For FET transistors every point can be a G (Gate), D (Drain) or S (Source). If the sequence of the test pins is not 1, 2 and 3 in the reading direction, you can invert the sequence with the option EBC STYLE=321 . The pin assignment is then shown with style ”321=...”, which will better match the usual reading direction.
Example: CFLAGS += EBC STYLE

NO NANO specifies that the decimal prefix nano will not be used to display the measurement results. So capacity values will be shown in µF instead of nF.
Example: CFLAGS += NO NANO

PULLUP DISABLE specifies, that you don’t need the internal pull-up resistors. You must have installed a external pull-up resistor at pin 13 (PD7) to VCC, if you use this option. This option prevents a possible influence of pull-up resistors at the measuring ports (Port B and Port C). example: CFLAGS += -DPULLUP DISABLE

ANZ MESS this option specifies, how often an ADC value is read and accumulated. You can select any value between 5 and 200 for building mean value of one ADC measurement. Higher values result to better accuracy, but longer measurement time. One ADC measurement with 44 values takes about 5ms.
example: CFLAGS += -DANZ MESS=25

POWER OFF This option enables the automatic power off function. If you don’t specify this option, measurements are done in a loop infinitely until power is disconnected with a ON/OFF switch. If you have the tester without the power off transistors, you can deselect the option POWER OFF.

If you have NOT selected the POWER OFF option with the transistors installed, you can also shut down the tester. During displaying the measurement result you should hold the start key pressed for several seconds until the ”Timeout” message is displayed. If you then release the key, the tester will be shut off.

You can also specify, after how many measurements without a founded part the tester will shut down. The tester will also shut down the power after twice as much measurements are done in sequence without a single failed part search. If you have forgotten to unconnect a test part, total discharging of battery is avoided. Specify the option with a form like CFLAGS += -DPOWER OFF=5 for a shut off after 5 consecutive measurements without part found. Also 10 measurements with any founded part one after another will shut down. Only if any sequence is interrupted by the other type, measurement continues. The result of measurement stay on the display for 14 seconds for the single measurement, for the multiple measurement version display time is reduced to 5 seconds (set in config.h). If the start key is pressed a longer time on power on time, the display time is also 14 seconds for the multiple measurement. The maximum value is 255 (CFLAGS += -DPOWER OFF=255).
example 1: CFLAGS += -DPOWER OFF=5
example 2: CFLAGS += -DPOWER OFF

BAT CHECK enables the Battery Voltage Check. If you don’t select this option, the version number of software is output to the LCD instead. This option is usefull for battery powered tester version to remember for the battery change.
example: CFLAGS += -DBAT CHECK

BAT OUT enables Battery Voltage Output on LCD (if BAT CHECK is selected). If your 9V supply has a diode installed, use the BAT OUT=600 form to specify the threshold voltage (mV) of your diode to adjust the output value. Also the voltage loss of transistor T3 can be respected with this option. threshold level does not affect the voltage checking levels (BAT POOR). example 1: CFLAGS += -DBAT OUT=300
example 2: CFLAGS += -DBAT OUT

BAT POOR sets the poor level of battery voltage to the specified 1mV value. The warning level of battery voltage is 0.8V higher than the specified poor level, if the poor level is more than 5.3V. If the poor level is 5.3V or less, the warning level is 0.4V higher. If the poor level is below 3.25V, the warning level is only 0.2V higher than the selected poor level and if the poor level is below 1.3V, the warning level is only 0.1V higher than the specified poor level. Setting the poor level to low values such as 5.4V is not recommended for rechargeable 9V batteries, because this increase the risk of battery damage by the reason of the deep discharge! If you use a rechargeable 9V Battery, it is recommended to use a Ready To Use type, because of the lower self-discharge.
example for low drop regulator (5.4V): CFLAGS += -DBAT POOR=5400
example for 7805 type regulator (6.4V): CFLAGS += -DBAT POOR=6400

INHIBIT SLEEP MODE disable the use of the sleep mode of the processor. Normaly the software uses for longer work breaks the sleep mode to avoid unneeded current consumption. The usage of this sleep mode indeed spare battery capacity, but produce additional stress for the voltage regulator.
example: CFLAGS += -DINHIBIT SLEEP MODE

PROGRAMMER select your programmer type for avrdude interface program. The correct selection of this option is needed, if you use the “make upload” or “make fuses” call of this Makefile. For further information please look to the manual pages of avrdude and online documentation [12].
example: PROGRAMMER=avrisp2

BitClock selects the Bit clock period for the Programmer. See the description of the -B parameter of avrdude.
example: BitClock=5.0

PORT select the port where avrdude can reach your microcontroller (atmega). For further information please look to the manual pages of avrdude.
example: PORT=usb

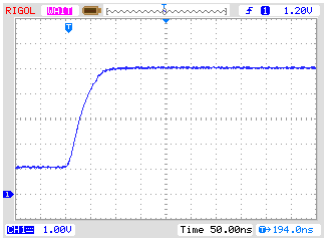
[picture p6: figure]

(a) from 5V to 1.1V | (b) from 1.1V to 5V

Figure 4.1: AREF switching with a 1nF Capacitor

Additional parameters can be set in the files transistortester.h and config.h . The file transistortester.h contains global variables and defines the port / pin constellation and the resistor values used for measurement. The file config.h specifies parameter for different processor types, wait times and the clock frequency of the ADC. Normally there is no reason to change these values.

# Chapter 5

# Description of the measurement procedures

The simplified schematic of a Input/Output-Port pin of the ATmega is shown in figure 5.1. The PUD switch isolates all “pull up” resistors of the ATmega. The output of a pin can be switched off with the DD switch. The Input can operate regardless to the state of the switch DD. The PORT switch usually defined the output level, but also switches the pull up resistor. Because the Switches PORT and DD can not be changed at the same time but only one after another, the pull up resistors can disturb the measurement. Therefore I prefere to disable the pull up resistors with the PUD switch. Of course all the switches are electronic type and the resistors 19Ω and 22Ω are approximated values.

Figure 5.1: simplified diagram of each ATmega port pin

Every of the three terminal probes of your Transistor Tester is build with three ATmega port pins, which is shown as simplified diagram for the terminal probe TP2 (middle of three pins) in figure 5.2.

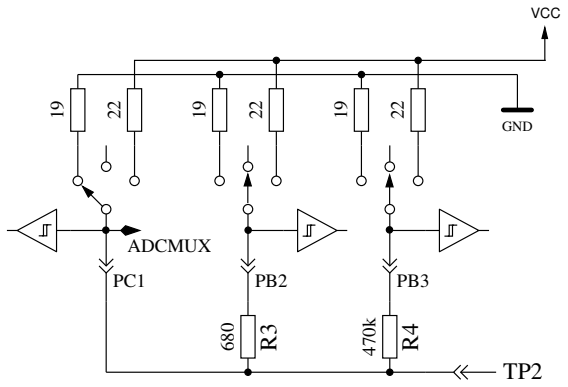
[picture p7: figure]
ADCMUX; GND; VCC

Figure 5.2: simplified circuit of each measurement terminal probe TP

Every test pin (measurement port) can be used as digital or analog input. This measurement capability is independent of using the port as output. Every test pin can be switched to output and in this mode it can be directly connected to GND (0V) or VCC (5V), or it can be connected via a 680Ω resistor or a 470kΩ resistor to either GND or VCC. Table 5.1 shows all possible combination of measurements. Notice, that the positive state can be switched directly to VCC (Port C) or it can be connected with the 680Ω resistor to VCC (Port B). The same possibility has the negative state of terminal probe to the GND side. The test state means, that probe can be open (Input), connected with the 470kΩ resistor to VCC or GND, or that the probe can be connected with the 680Ω resistor to VCC or GND.

| state pin 1 | state pin 2 | state pin 3
1. 2. 3. 4. 5. 6. | positive positive test test negative negative | negative test negative positive test positive | test negative positive negative positive test

Table 5.1: all combinations of measurement

If the capacitor measuring is configured for the tester, the tester will try to discharge the capacitors connected at all test pins. If discharge will fail, that means the remaining voltage is to high, the discharging will be aborted after about 12 seconds with the meassage ”Cell!”. This can also be happen, if no capacitor is connected to any test pin. The cause for this can be, that the cut-off voltage is choosed to low for this ATmega. You can choose a higher voltage with the Makefile option CAP EMPTY LEVEL.

## 5.1 Measurement of Semiconductors

One probe pin is assumed to be the negative side of the component. Another pin is assumed to be the positive side of the component. For a first test, the components positive side is directly connected to VCC. The negative side is connected with the 680Ω resistor to GND. The test probe (third pin, also called TriStatePin) is first connected with the 680Ω resistor for 10 ms to GND. The voltage of the negative probe pin is read, during the TriStatePin is switched to Input (High Impedance). It is assumed that the tested part can be a N-Channel MOSFET and the gate should be discharged. If the readed voltage is above 976mV, the next test assume, that the tested part can also be a P-Channel MOSFET and for this a 10ms switch of the TriStatePin with the 680Ω resistor to the VCC side is done. Also for this case the voltage at the negative Probe pin is read with a currentless TriStatePin. If the voltage of the negative pin is greater than 455mV, additional tests are made to differ N-Channel JFET or D-MOSFET (depletion) and P-Channel JFET or P-MOSFET. The MOSFET versions can be differed by the missing of gate current in any state of the TriStatePin.
To get parameters of the depletion types, they will be measured with a 680Ω resistor at the source pin, as shown in figure 5.3 . This measurement will be done instead of the usually measurement of current with the gate hold at source level, because the IDSS current of the FET transistor can often not be reached with the relative high resistance of the 680Ω resistor.

Figure 5.3: Measurement of the Gate-Source voltage and Source current of a N-JFET transistor

If the component has no current between positive probe and negative probe without signal at the TristatePin, the next tests are specified in the next section 5.1.1. If current was detected, the next test is described in the diode section 5.1.3.

### 5.1.1 Measurement of PNP Transistor or P-Channel-MOSFET

First the current amplification factor is measured with common collector for the assumed PNP transistor. The measuring situation is shown in figure 5.4. If the measured voltage at the Base (UB)

is above 9mV with the 680Ω resistor, the hFE is build as hF E =

UE−UB
UB . The voltage UE is the difference of the Emitter-voltage to VCC. The difference between the 22Ω and 19Ω resistors are not respected. If the UB voltage is below 10mV, the measurement is done with the 470kΩ resistor at
the base. In this case the current amplification factor is build as hF E = | UE·470000
| UB·(680+22) .

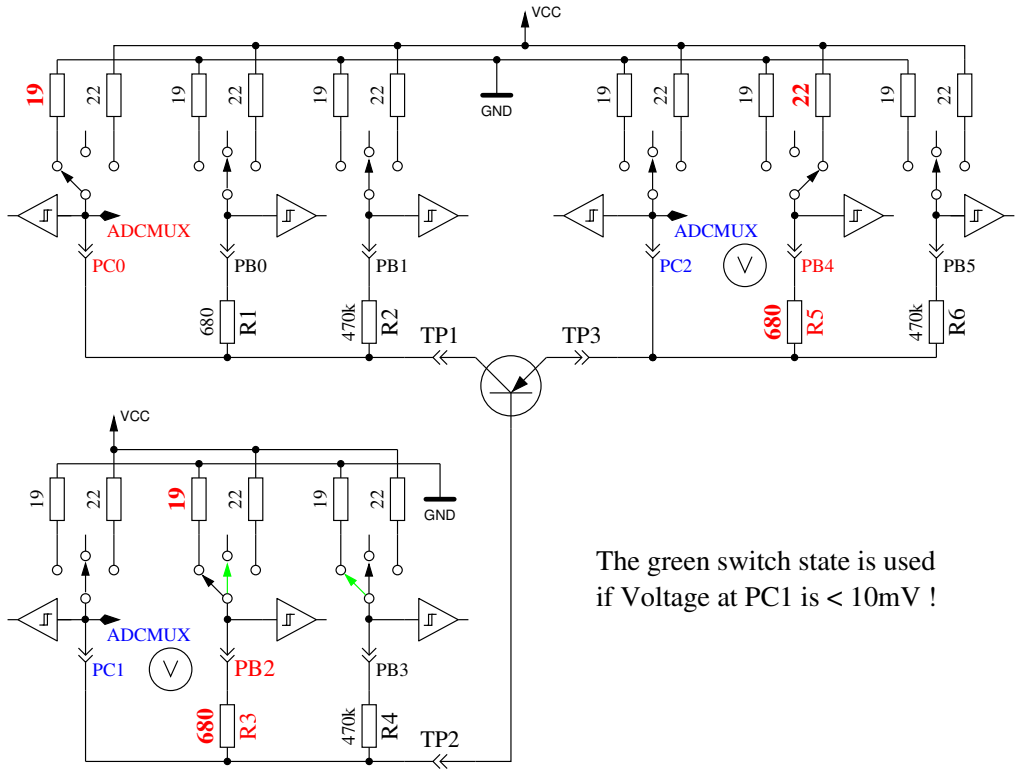
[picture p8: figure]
ADCMUX; GND; The green switch state is used if Voltage at PC1 is < 10mV !; VCC

Figure 5.4: hFE measurement of PNP transistor with common collector circuit

Next the tests with common emitter are done for the assumed PNP transistor. The positive side of component is now direct connected to VCC, the negative side 680Ω resistor is connected to GND as shown in Figure 5.5. If the negative side of component has a voltage of above 3.4V, when the base side 680Ω resistor was connected to GND, it must be a PNP transistor or a P-Channel FET. This can be easy find out by analysing the base voltage. If the base voltage is greater 0.97V, it must be a PNP. For measuring the current amplification factor, the 470kΩ resistor is taken as Base resistor instead of the 680Ω. The current amplification factor is build by hF E =

(UC−UC0)·470000
UB·(680+19) .
The voltage UC0 is the voltage at the colletor resistor without base current. The higher current amplification factor is assumed to be the right one, this one or the one found with the common collector circuit. From version 1.08k the current amplification factor with common emitter circuit is only build for processors with more than 16k flash memory like ATmega328. For the other processors only the common collector circuit is used.
The values found for the PNP are only valid, if a second set of measurements is done. In order to prevent detecting the PNP in the inverse mode (collector and emitter are swapped), the measurement with the higher current amplification is taken as the right one. If base voltage is lower than 0.97V, it must be a P-E-MOS. In this case the gate threshold voltage is measured by switching the gate slowly with the 470kΩ resistor up and down, waiting for a digital input signal change of the Drain side and then read the voltage of the gate pin.

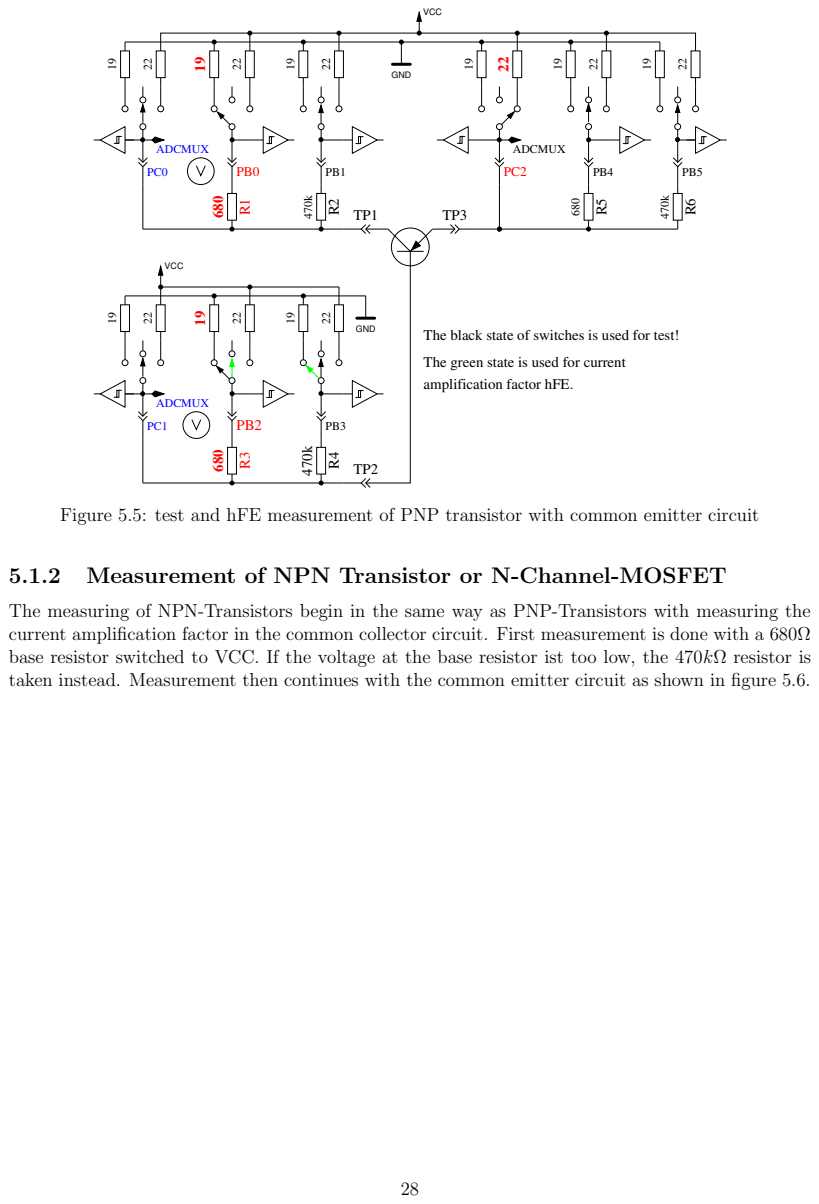
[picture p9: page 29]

The black state of switches is used for test!

The green state is used for current
amplification factor hFE.

Figure 5.5: test and hFE measurement of PNP transistor with common emitter circuit

5.1.2 Measurement of NPN Transistor or N-Channel-MOSFET

The measuring of NPN-Transistors begin in the same way as PNP-Transistors with measuring the
current amplification factor in the common collector circuit. First measurement is done with a 680Ω
base resistor switched to VCC. If the voltage at the base resistor ist too low, the 470kΩ resistor is
taken instead. Measurement then continues with the common emitter circuit as shown in figure 5.6.

The black state of switches is used for test!

The green state is used for current ²² | 22

Figure 5.6: test and hFE measurement of NPN transistor with common emitter circuit

If the voltage of collector sinks below 1.6V, when the 680Ω base resistor is connected to VCC, ist must be a NPN, N-Channel MOSFET or Thyristor/Triac. With two simple tests a Thyristor or Triac can be identified. If the gate pin resistor is connected for 10ms to GND and than made currentless, the current at the anode should stay. If then the anode resistor is short connected to GND and reconnected to VCC, the Thyristor should not trigger again (no current). Please keep in mind, that only low power Thyristors can be tested, because the holding current of the tester can reach only 6mA. If both tests attest a Thyristor, further tests with reverse polarity are done to exclude or confirm a Triac.
If neither Thyristor nor Triac could be confirmed, it can be a NPN or N-Channel E-MOSFET. The Base voltage of a NPN Transistor will be near the Emitter voltage, so this type can be identified definitely. The current amplification factor in the common emitter circuit is build by hF E =

(V CC−UC−UC0)·470000
(V CC−UB)·(680+22) . If the voltage of the Base or better Gate shows, that there is no or little current, part will be a N-Channel E-MOS (Enhancement MOSFET). In this case the threshold voltage is measured by switching the Gate slowly with the 470kΩ resistor to VCC and GND, waiting for a digital input signal change of the Drain side and then read the voltage of the Gate pin. This measurement is done eleven times with ADC results accumulated as shown in Figure 5.7. The result is multiplied by four and divided by 9 to get the voltage in mV resolution.

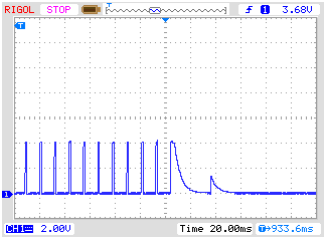
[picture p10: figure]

Figure 5.7: measuring of threshold voltage of N-Channel-MOSFET

### 5.1.3 Measurement of Diodes

If current is detected with the pre-tests, the behavior of the part will be checked to be a diode. The flow voltage with the 680Ω resistor must be between 0.15V and 4.64V. The flux voltage with the 680Ω must be greater than 1.125 times the flux voltage with the 470kΩ resistor and sixteen times the flux voltage with the 470kΩ must be greater than the flux voltage with the 680Ω resistor. Additionally the afterward renewed measurement with the 470kΩ resistor should not have a higher voltage than the previous measurement with the 680Ω resistor. I hope, that this behavior identifies always a diode. The identification of a diode by no current flow in the opposite direction is not possible with a inverse parallel diode. If only a single diode is detected, the residual current in reverse direction is measured with the 470kΩ resistor at 5V. The resolution is about 2nA. If the residual current is greater as 5.3µA (voltage at the 470kΩ is more than 2.5V), the measurement is done with the 680Ω instead. Then the resolution is only about 1µA. Furthermore the capacity in reverse direction is also measured for single diodes.

### 5.1.4 Results of different measurements

The following three tables shows results of different test probes with one ATmega8 processor and two different software versions of a ATmega168 processor. The measurement of the inverse capacity value for the double diode MBR4045PT is only possible with cooling. This will be caused by high residual current of this 40A diode. Also the capacity value of the inverse base emitter diode of the germanium transistor AC128 can only be measured with cooling.

Diode Type | Mega8@8MHz | Mega168 @8MHz | Mega328 @8MHz
1N4148 | Diode, 715mV, 1pF | Diode, 718mV, 0pF, 2nA | Diode, 715mV, 1pF, 4nA
1N4150 | Diode, 665mV, 1pF | Diode, 672mV, 1pF, 4nA | Diode, 666V, 2pF, 6nA
BA157 | Diode, 619mV, 19pF | Diode, 621V, 17pF, 12nA | Diode, 615mV, 18pF, 12nA
BY398 | Diode, 538mV, 16pF | Diode, 541mV, 14pF, 63nA | Diode, 537mV, 15pF, 63nA
1N4007 | Diode, 650mV, 13pF | Diode, 655mV, 10pF, 6nA | Diode, 650mV, 13pF, 6nA
LED green | Diode, 1.96V, 5pF | Diode, 1.95V, 4pF | Diode, 1.95V, 4pF
ZPD2,7 | 2xDi, 743mV, 2.53V | 2xDi, 737mV, 2.52V | 2xDi, 733mV, 2.51V
BU508A B+E | Diode, 609mV, 5.15nF | Diode, 611mV, 5.20nF, 0.39uA | Diode, 606mV, 5.25nF, 0.4uA
BU508A B+C | Diode, 582mV, 256pF | Diode, 586mV, 255pF, 21nA | Diode, 587mV, 259pF, 19nA
AC128 B+E | Diode, 272mV, 0pF | Diode, 277mV, 0pF, 2.2uA | Diode, 273mV, 0pF, 2.3uA
AC128 B+E cooled | | | Diode, 349mV, 140pF, 0.57uA
MBR20100CT | 2xDi, 337mV, 337mV | 2xDi, 338mV, 338mV | 2xDi, 336mV, 335mV
MBR20100CT | Diode, 337mV, 345pF | Diode, 339mV, 351pF, 29nA | Diode, 337mV, 350pF, 25nA
MBR4045PT cooled | Diode, 243mV, 1.80nF | Diode, 233mV, 1.94nF, 1.7uA | Diode, 235mV, 1.95nF, 1.8uA
SF38G | Diode, 519mV, 107pF | Diode, 521mV, 105pF, 2nA | Diode, 516mV, 106pF, 2nA

Table 5.2: measurement results of diode testing

Transistor Type | Mega8@8MHz | Mega168 @8MHz | Mega328 @8MHz
BU508A | NPN, B=9, 602mV | NPN, B=10, 594mV | NPN, B=9, 591mV
2N3055 | NPN, B=20, 553mV | NPN, B=22, 545mV | NPN, B=21, 542mV
BC639 | NPN, B=180, 628mV | NPN, B=215, 623mV | NPN, B=173, 620mV
BC640 | PNP, B=216, 635mV | PNP, B=178, 635mV | PNP, B=183, 600mV
BC517 | NPN, B=26.1k, 1.20V | NPN, B=27.8k, 1.21V | NPN, B=26.1k, 1.20V
BC516 | PNP, B=77.6k, 1.20V | PNP, B=81.1k, 1.19V | PNP, B=81.7k, 1.18V
BC546B | NPN, B=381, 659mV | NPN, B=380, 653mV | NPN, B=430, 675mV
BC556B | PNP, B=285, 689mV | PNP, B=250, 688mV | PNP, B=262, 654mV
AC128 (Ge.) | PNP, B=63, 190mV | PNP, B=61, 184mV | PNP, B=59, 182mV
BRY55/200 | Thyristor | Thyristor | Thyristor
MAC97A6 | Triac | Triac | Triac

Table 5.3: measurement results of bipolar transistor testing

Some results are different to the earlier results of the software of Markus Frejek. For example a darlington transistor BC517 has been measured by the older software with a hFE of 797 . and a base emitter voltage of 1438mV. This will be caused by the additional measurement of current amplification with common collector circuit. The base emitter voltage is measured by the older Version as separate diode test with 1438mV. Now the base emitter voltage is measured with the state of current amplification testing (1.20V).
The following table shows the measurement results for germanium transistors, which are extra problematic to measure because of the temperatur dependent and high residual collector current. The results of the original version of Markus F. and the results of the actual 1.08k version are compared together. The 1.08k version for a ATmega328 measures the current amplification factor with common collector and common emitter circuit, the higher result will be shown. The 1.08k version for the ATmega168 measures only with common collector circuit.
Transistor Type | Mega8@1MHz Original Version Markus F. | Mega168 @8MHz Version 1.08k | Mega328 @8MHz Version 1.08k
AC128 | PNP, B=52, 279mV | PNP, B=61, 185mV | PNP, B=60, 190mV
AC116-65 | PNP, B=505, 378mV | PNP, B=56, 237mV | PNP, B=76, 144mV
AC116-145 | PNP, B=485, 294mV | PNP, B=83, 212mV | PNP, B=167, 156mV
AC176-65 | NPN, B=98, 235mV | NPN, B=52, 146mV | NPN, B=57, 97mV
GC122 | PNP, B=84, 368mV | PNP, B=56, 186mV | PNP, B=58, 117mV
GC301 | PNP, B=48, 289mV | PNP, B=40, 183mV | PNP, B=40, 189mV

Table 5.4: Measurement results of bipolar junction germanium transistors

FET Type | Mega8@8MHz | Mega168 @8MHz | Mega328 @8MHz
ZVNL120A | N-E-MOS,D, 1.6V 147pF | N-E-MOS,D, 1.5V 139pF | N-E-MOS,D, 1.5V 140pF
IRF530N | N-E-MOS,D, 3.6V 1.55nF | N-E-MOS,D, 3.6V 1.54nF | N-E-MOS,D, 3.6V 1.56nF
BS170 | N-E-MOS,D, 2.6V 78pF | N-E-MOS,D, 2.6V 68pF | N-E-MOS,D, 2.6V 70pF
IRL3803 | N-E-MOS,D, 2.3V 9.81nF | N-E-MOS,D, 2.3V 9.71nF | N-E-MOS,D, 2.3V 9.80nF
IRFU120N | N-E-MOS,D, 4.2V 909pF | N-E-MOS,D, 4.2V 913pF | N-E-MOS,D, 4.2V 920pF
BUZ71A | N-E-MOS,D, 3.2V 714pF | N-E-MOS,D, 3.2V 708pF | N-E-MOS,D, 3.2V 714pF
ZVP2106A | P-E-MOS,D, 3.2V 122pF | P-E-MOS,D, 3.2V 115pF | P-E-MOS,D, 3.2V 117pF
IRF5305 | P-E-MOS,D, 3.6V 2.22nF | P-E-MOS,D, 3.6V 2.22nF | P-E-MOS,D, 3.6V 2.24nF
BS250 | P-E-MOS,D, 2.6V 53pF | P-E-MOS,D, 2.6V 43pF | P-E-MOS,D, 2.6V 44pF
IRFU9024 | P-E-MOS,D, 3.5V 937pF | P-E-MOS,D, 3.6V 945pF | P-E-MOS,D, 3.5V 952pF
J310 Idss=24-60mA | N-JFET I=3.1mA Vgs=2.2V | N-JFET I=3.1mA Vgs=2.2V | N-JFET I=3.1mA Vgs=2.2V
2N5459 Idss=4-16mA | N-JFET I=2.1mA Vgs=1.5V | N-JFET I=2.1mA Vgs=1.5V | N-JFET I=2.1mA Vgs=1.5V
BF256C Idss=11-18mA | N-JFET I=3.4mA Vgs=2.4V | N-JFET I=3.4mA Vgs=2.4V | N-JFET I=3.4mA Vgs=2.4V
BF245A Idss=2-6mA | N-JFET I=1.1mA Vgs=.75V | N-JFET I=1.1mA Vgs=0.75V | N-JFET I=1.1mA Vgs=0.75V
BF245B Idss=6-15mA | N-JFET I=2.5mA Vgs=1.7V | N-JFET I=2.5mA Vgs=1.7V | N-JFET I=2.5mA Vgs=1.7V
BF245C Idss=12-25mA | N-JFET I=3.9mA Vgs=2.7V | N-JFET I=3.9mA Vgs=2.7V | N-JFET I=3.9mA Vgs=2.7V
J175 Idss=7-60mA | P-JFET I=3.2mA Vgs=2.2V | P-JFET I=3.2mA Vgs=2.2V | P-JFET I=3.2mA Vgs=2.2V
2N5460 Idss=1-5mA | P-JFET I=0.78mA Vgs=0.54V | P-JFET I=0.77mA Vgs=0.54V | P-JFET I=0.78mA Vgs=0.54V

Table 5.5: measurement results of MOS transistor testing

## 5.2 Resistor Measurement

Each resistor is measured with four different types of measurement in one current direction. The same resistor ist also tested with the same four measurement types in the other current direction. The measurement in the opposite direction is only used to identify a resistor. If mismatch between both measurements is too big, it’s not a resistor.

### 5.2.1 Resistor Measurement with 680 Ohm Resistors

The measurement of a unknown resistor Rx is done in two ways with the build in precision 680Ω resistors. The diagram of this measurements for test pin 1 (TP1) and test pin 3 (TP3) are simplified shown in figure 5.8 and figure 5.9 as a example of the six choises of probe combinations.

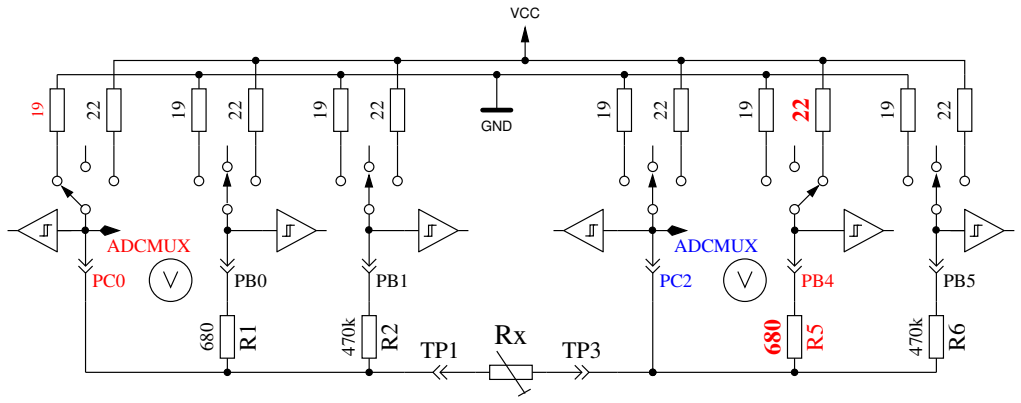
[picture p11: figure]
ADCMUX; GND; VCC

Figure 5.8: Measurement type 1 with 680Ω

Figure 5.9: Measurement type 2 with 680Ω

On the left side test pin 1 is shown and on the right side you can see test pin 3. In both diagrams you see, that the terminal 3 (right side) is connected to VCC, the left side is connected to GND. The direction of current flow through the resistor Rx is allways the same. The values of ports switched to output are shown with red color, the values of ports used as Input are shown in blue color, the inactive ports are black. In both shown measurement types the current should have the same value, because the sum of resistor values between VCC and GND is identical (if the build in resistors are identical). Usually the measured voltage is not the same, because the sequence of resistors has changed.

The V symbol within the circle marks the ports used for voltage measurement. In both configu-rations the value of resistor Rx can be computed with the known resistor values and the measured voltages, if the relation of resistor Rx and the 680Ω is not too high. The theoretical voltage gradient is shown in figure 5.10, where resistor values are shown in logarithmic scale.

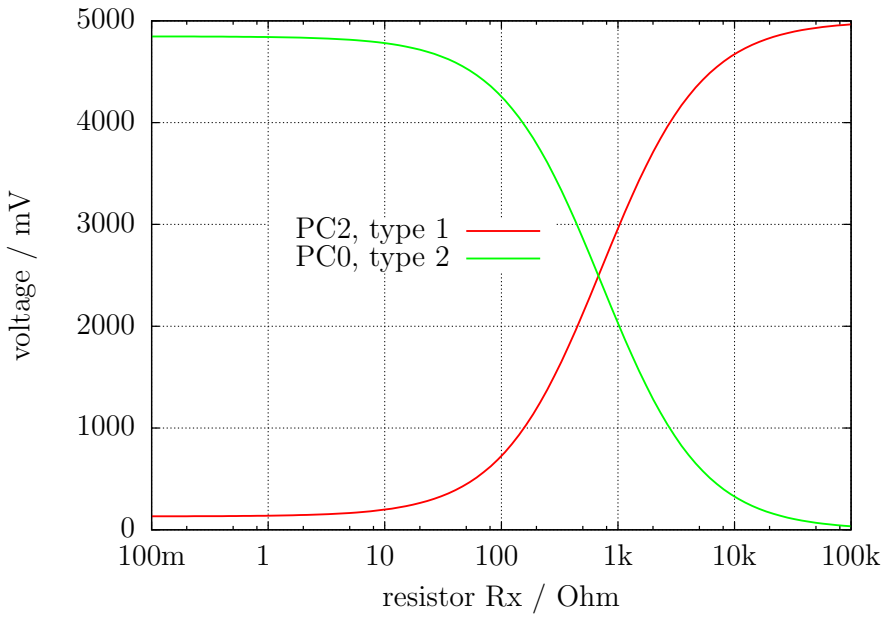
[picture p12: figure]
voltage / mV; resistor Rx / Ohm; PC2, type 1 PC0, type 2

Figure 5.10: Voltages of type 1 and type 2 measurements with 680Ω

The graph of measurement type 1 is shown in figure 5.11a with zoomed scale for the lower resistor range. You can see, that you need a better ADC resolution than the standard 4.9mV resolution at the 5V ADC reference, to get the right resistor value from measured voltage below 2Ω. There are only three ADC steps from 0Ω to 2Ω. The range switching with the AUTOSCALE ADC option can help in this case. The same zoomed range of measurement type 2 shows the figure 5.11b. Unfortunately we can not use the higher ADC resolution for measurement type 2 in this range, because the voltage is too high and our ATmega have no differential ADC input. Measurements with the 680Ω resistors are taken for building the result of measurements up to 20kΩ (Voltage of measurement type 2 will be below 169mV).
For higher resistor values the measurements with the 470kΩ resistors are used. The mean value of both measurements is taken as displayed resistor value, if all tests attests, that it is no other type of part. If the AUTOSCALE ADC function is selected and one of the voltages of the both measurement types is below 0.98V, a weighted average is build with factor four for this value. The other value is weighted with factor one. This is done to respect the factor four better resolution of this measurement. Factor four is only taken for ATmega168 and ATmega328 processors, for the ATmega8 two is taken as weighting factor if voltage is below 0.98V, because the reference voltage for the ADC is here 2.54V instead of 1.1V . If the ATmega has more than 8KByte flash memory, the voltage measurement at the resistors will be delayed until no more changes are detected or the time limit is reached. With this method big capacitors are no more detected as resistors by mistake and the DC resistance of big inductors will be measured correctly.

(a) Type 1 measurement

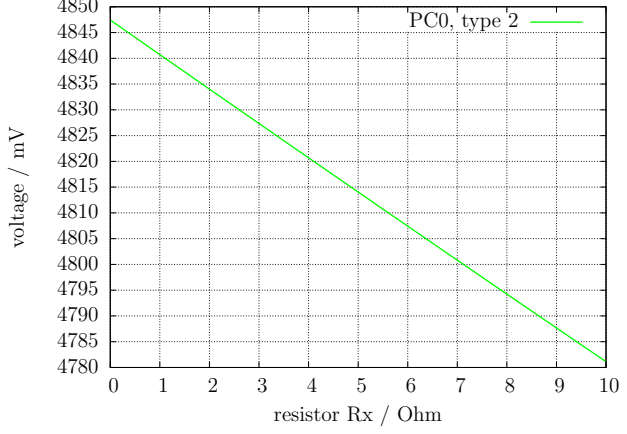
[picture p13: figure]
voltage / mV; resistor Rx / Ohm; type

(b) Type 2 measurement

Figure 5.11: Cut-out of theoretical Voltage from 0Ω to 10Ω

### 5.2.2 Resistor Measurement with 470 kOhm resistors

The next figures 5.12 and 5.13 shows the same measurement procedure for the measurement with the precision 470kΩ resistors. Because the 470kΩ is very big in relation to the port resistor values 22Ω and 19Ω, the port resistor values are ignored for the computing of the resistor value Rx.
For both measurement types with the 470kΩ resistors only one Voltage is measured, because the current is so low, that no voltage difference at the internal port resistors of the ATmega can be measured (as expected). The theoretical voltage gradient is shown in figure 5.14 where the resistor values are again shown in logarithmic scale. The theoretical gradient in this diagram ends at 100MΩ, but the resulting value of the Tester is limited to 60MΩ, otherwise the Tester assumes that no resistor is connected. The weighted average of both measurement types is taken as result with the same rules described for the measurements with the 680Ω resistors. For all ATmega processors I had found, that the measured results with the 470kΩ resistors are more exactly, if a constant offset of 350Ω will be added. This offset can be adjusted with the RH OFFSET define in the config.h file.

Figure 5.12: Measurement type 3 with 470kΩ

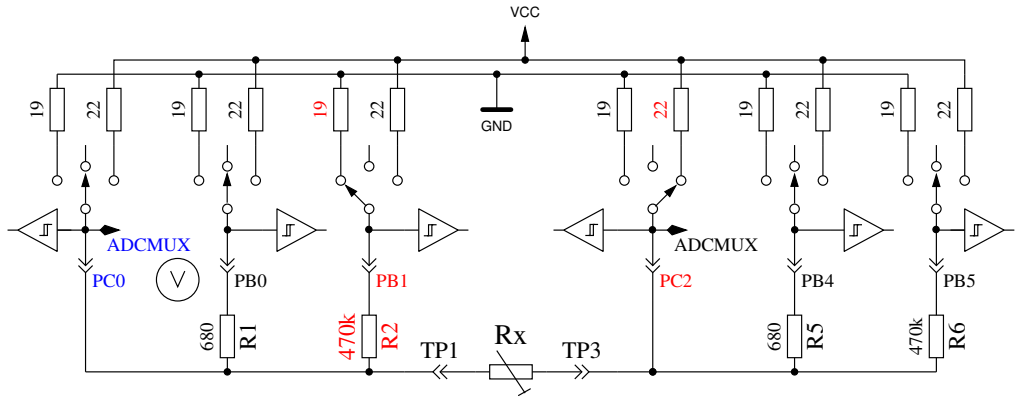
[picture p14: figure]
ADCMUX; GND; VCC

Figure 5.13: Measurement type 4 with 470kΩ

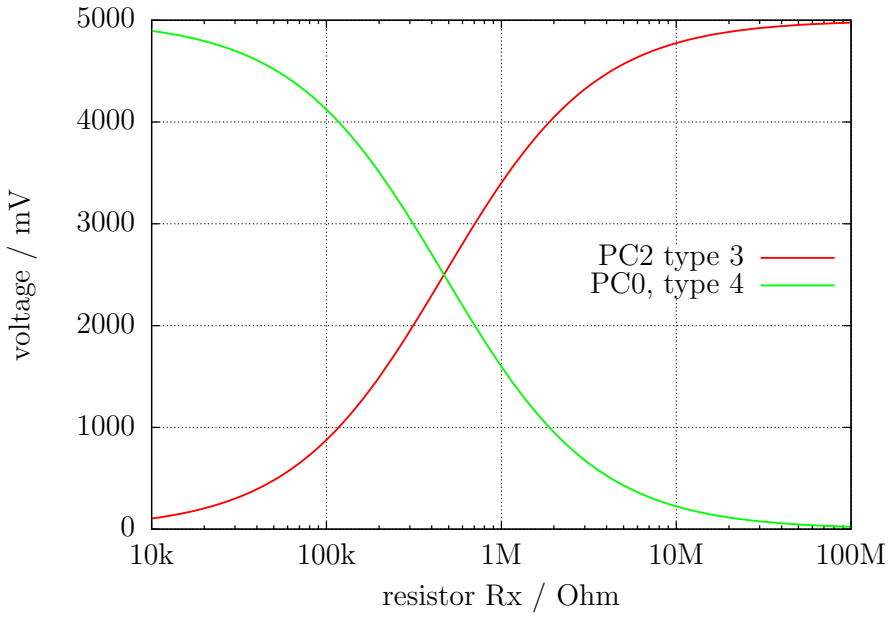
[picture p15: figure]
voltage / mV; resistor Rx / Ohm; PC2 type 3 PC0, type 4

Figure 5.14: Voltages of type 3 and type 4 measurements with 470kΩ

### 5.2.3 Results of the resistor measurements

Figure 5.15 shows the relative errors of the resistor measurements with three ATmega8 microcontrollers. Additionally some results with the original software of Markus F. with one ATmega8 are shown as ”Mega8orig” in this figure. More measurements results with ATmega8A and ATmega8L are shown in figure 5.16a and 5.16b. Figure 5.17 shows the same measurements with a ATmega168 microcontroller. Mega168 are the results without the AUTOSCALE ADC option, Mega168as are the same measurements with the AUTOSCALE ADC option. With the ATmega168 microcontroller it seems to be possible, that measurements of resistors in the range from 20Ω to 20MΩ can be measured with a tolerance of ±1%. For Measurements below 100Ω you should keep in mind, that any measurement probe with wire have a resistance too. It is better to connect the resistor directly to the terminal pins. If this is not possible, subtract the resistance value of the shortened probe. For example, if your Resistor have a printed value of 30Ω, your tester shows a value of 30.6Ω and the two probes shortened have a value of 0.5Ω, then your resistor has been measured with 30.1Ω. Below a resistance value of 10Ω one resolution step results to a error of more than 1%!

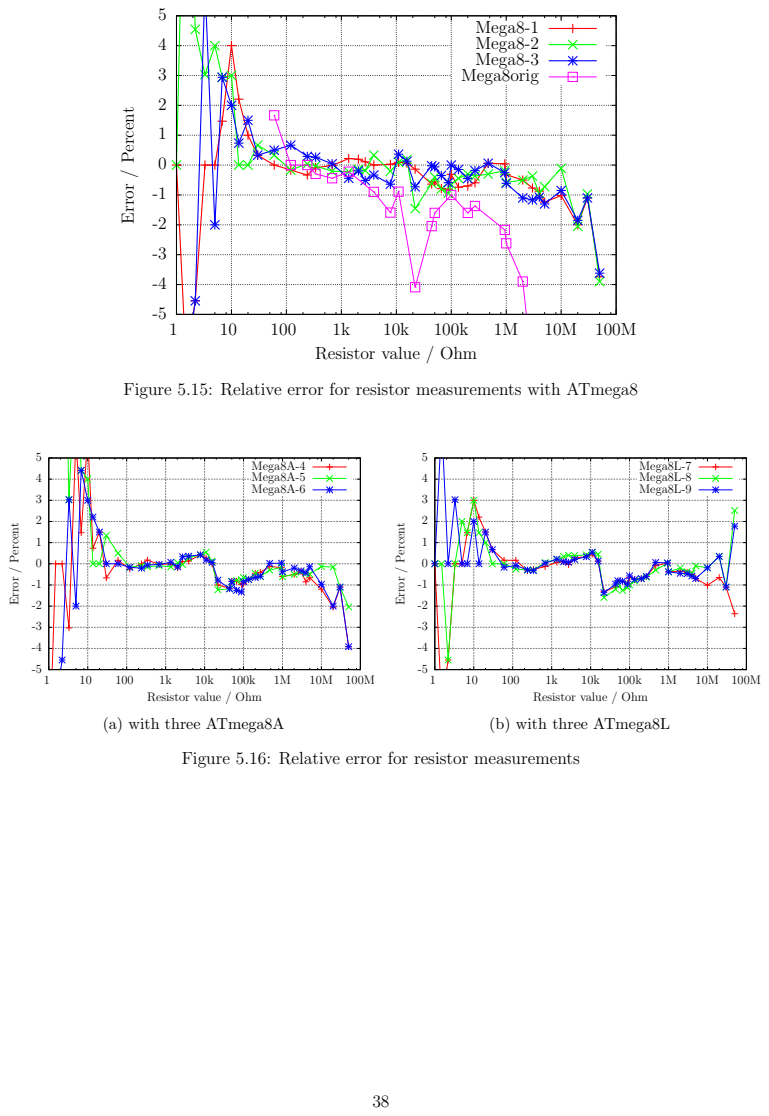
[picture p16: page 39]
Error / Percent; Mega8A-4 Mega8A-5 Mega8A-6; (a) with three ATmega8A; Mega8L-7 Mega8L-8 Mega8L-9; (b) with three ATmega8L

Mega8-1 Mega8-2

Mega8-3 Mega8orig

Resistor value / Ohm

Figure 5.15: Relative error for resistor measurements with ATmega8

Figure 5.16: Relative error for resistor measurements

Figure 5.17: Relative error for resistor measurements with ATmega168

The figure 5.18a shows the measurement errors of three ATmega168 processors before calibration as points, after the calibration as line. The equivalent measurement errors of three ATmega168A prozessors are shown in figure 5.18b and the measurement errors of three ATmega168P prozessors are shown in figure 5.19 . The measurement errors of three ATmega328 prozessors are shown in figure 5.20a and 5.20b. After the automatic calibration the relative measurement errors of resistors between 10 Ω − 20MΩ usually are in the limit ±1 %. Only one measurement of a 22kΩ resistor with the ATmega328P-13 shows a higher error. Before the calibration errors of some processors are found with ± 3%. This will be caused by the AUTOSCALE ADC switching of the ADC reference. The direct compare of a capacitor voltage below 1 V, once measured with the VCC reference and another once measured with the internal reference, can adjust this error. With this measurement condition the voltage is measured with the same multiplexor channel and the internal bandgap reference is connected to the AREF pin of the ATmega. Unfortunately the direct measurement of the bandgap reference with the special multiplexor channel results to this offset, which can be manually adjusted with the REF R KORR option or automatically with the AUTO CAL option of the selftest. With the AUTO CAL option the REF R KORR value is a additional offset to the automatic find out value!

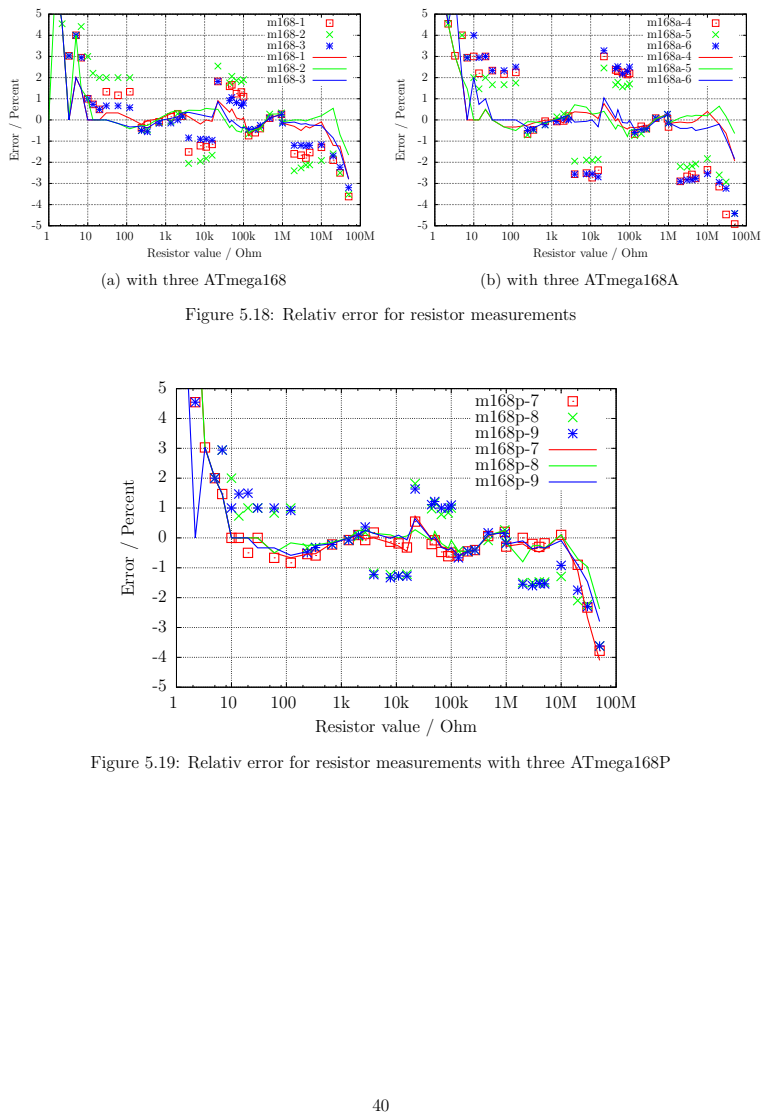
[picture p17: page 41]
Error / Percent; (a) with three ATmega168; (b) with three ATmega168A

Resistor value / Ohm

Figure 5.18: Relativ error for resistor measurements

m168p-8
m168p-9

Figure 5.19: Relativ error for resistor measurements with three ATmega168P

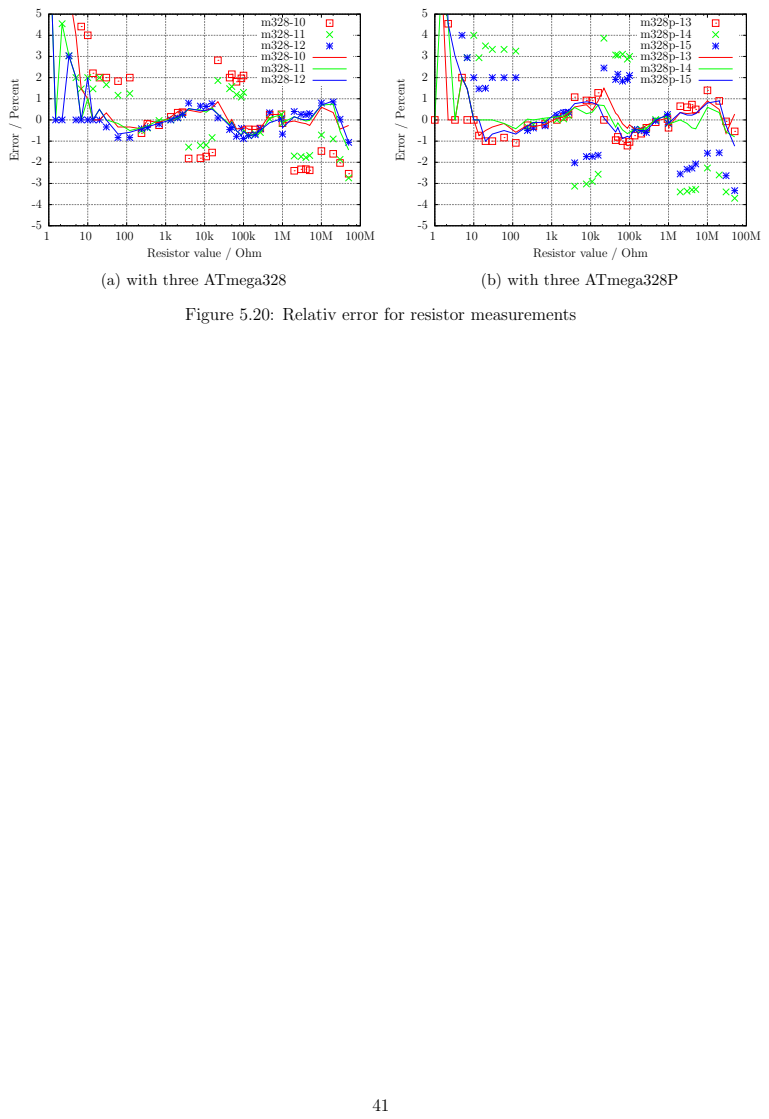
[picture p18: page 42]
Error / Percent; (a) with three ATmega328; (b) with three ATmega328P

Resistor value / Ohm

Figure 5.20: Relativ error for resistor measurements

## 5.3 Measurement of Capacitors

The measurement of capacitor values are done as separate task by measurement of load time after all other measurements. The original software of Markus F. did this with a program loop, which reads the corresponding digital input pin until a switch occured and count the loop cycles. This has the handicap, that the resolution of time measurement is limited by the time consumption of one loop cycle. This usually was done in all six combinations for all three probe pins. The actual software uses two different ways to get the load time in only three combinations for the three probe pins. The positive side is now always the higher probe number. Only if capacity is measured parallel with a diode, the polarity can be in the other order.

### 5.3.1 Discharging of Capacitors

You should always discharge the capacitor before connecting it to the tester. The tester additionally discharge the capacitor before any measurement. If the voltage is below 1300mV, the capacitor is shortened by the output pins of the connected ADC port (Port C). I believe that this is legal because every output port has a built in resistance of about 20Ω. The data sheet Figure 149 (page 258)
[2] shows voltage drop of output pins up to 2V. Of course I can not guaranty, that no damage can occur. I have tested the function with big capacitors of more than 15mF many times and I have never noticed any problem. The current should be below the specified limit of 40mA and is reduced fast by discharging. Off course damage can occur if you do not discharge a (high voltage) capacitor before connecting it to your tester.

### 5.3.2 Measurement of big Capacitors

One side of the capacitor is connected to GND. The other side of the capacitor is connected with the 680Ω resistor to VCC for a period of 10ms. Afterwards this probe pin is switched to Input (High Impedance). After this 10 ms current pulse the voltage of the capacitor is measured without any current. If the voltage has not reached a minimal value of 300mV, the load pulse is repeated up to 499 times. If after 127 pulses a minimum voltage of 75mV is not reached (about 2s), further load is stopped, because never the 300mV can be reached with the remaining load pulses. Figure 5.21 shows the three phases of measuring the capacity value of a capacitor. The value of the capacity is then computed with the count of load pulses and the reached load voltage from a table. The table contains the factors to get the capacity in nF units from load time and the reached voltage with a spacing of 25mV. Interim value of voltage will be interpolated.

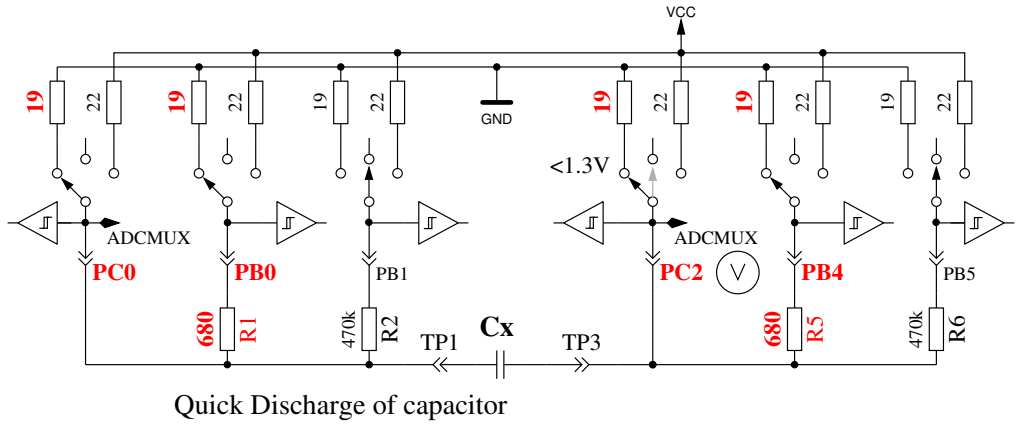
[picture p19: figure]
ADCMUX; GND; Quick Discharge of capacitor; VCC

Figure 5.21: discharge a capacitor and load with 10ms load pulses until voltage reach a value of 300mV

As a result of the low load voltage, the measurement is much faster than the initial software version, because this advantage works also on discharging. So bigger capacitors can be measured. Furthermore a diode, which is parallel connected to the capacitor dont disturb the measurement in most cases, because the flux voltage of most diodes is not reached. Figure 5.22a shows the charge and discharge for a 229µF capacitor. The flat top of diagram from load end to discharge begin is caused by the measuring and computing time of the ATmega. Figure 5.22b shows the same measurement for a 5mF capacitor, notice how the time for measurement is grown to about 1.5 seconds inclusive the discharge. The last example shows the capacity measuring of a 15mF capacitor in Figure 5.23

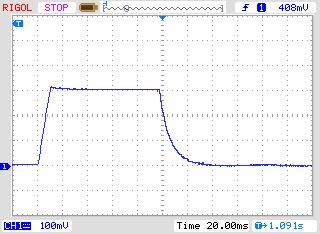
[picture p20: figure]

(a) 229µF Capacitor | (b) 5mF Capacitor

Figure 5.22: Charge and discharge of big Capacitors for measuring

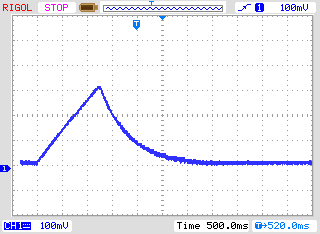
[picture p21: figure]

Figure 5.23: Charge and discharge of a 15mF Capacitor for measuring

After this capacity measurement the self-discharge of the capacitor will be checked by waiting a proportional period the loading has taken and reading the load voltage again. The measured capacity value is corrected due to this voltage drop. A test with a parallel connection of a 68µF capacitor and a 2.2kΩ resistor shows the effectivity of this method. The measured capacity value without the resistor is 66.5µF, with the parallel 2.2kΩ resistor results to a capacity value of 66.3µF. For comparison here are the results measured with a Peaktech 3315 multimeter: Without the resistor a capacity value of 68.2µF is measured, with the parallel 2.2kΩ resistor a value of 192µF is measured with the multimeter.

### 5.3.3 Measurement of small Capacitors

If the first 10 ms load pulse has overloaded the capacitor, another technique of measurement is used. The ATmega processor has a build in 16-Bit counter, which can operate at the full clock rate (1MHz or 8MHz). This counter has also the feature to save his counter value by a external event. This event can be built by the output of the comparator. The comparator can operate with any ADC input pin and the band gap reference. Figure 5.24 shows a simplified diagram of the measurement situation. So I discharge the capacitor, prepare the comparator to the proper pin input, start the counter at 0 and start immediately the charging of the capacitor with one side connected to GND and the other side connected with the 470kΩ resistor to VCC. Now I check within a program loop, if the counter flags signals a overflow event or a input capture (external) event. I count the overflow events until I detect the input capture event. In this case I stop the counter and check if I must count a additional overflow, because the counter can’t be stopped by the input capture event.
The input capture counter and the overflow counter built together the total time, from which we can get the capacity with a factor. The actual software can use a table with the theoretical dependency of the load time in respect to the comparator voltage. The table is spaced in 50mV steps and will be interpolated according to the actual reference voltage. This table will only be acticated with the Makefile option WITH AUTO REF. From the build capacity value I subtract a predefined experimental find out constant or a value found by the last selftest with AUTO CAL option to eliminate the zero offset. The zero offset may vary with printed board type, the used test equipment or processor. The selftest with AUTO CAL option will find out your zero offset automatically.
I noticed that the reference voltage is permanently somewhat to low, so that you can choose an offset with the Makefile option REF C KORR. After calibration with the AUTO CAL option , the REF C KORR will only be a offset to the measured difference voltage between loaded capacitor and internal reference. The measured reference voltage will then be corrected (added) by your value (mV units). If option WITH AUTO REF is not used, the reference voltages of ATmega8, ATmega168 and ATmega328 are applied as noted in the data sheets [2] [3]. A sample measurement of this type is shown in figure 5.25. The measurement time for the 22µF capacitor is above 2.6s because the 470kΩ is used for charging. But discharging is in this case much faster than charging.

Figure 5.24: measurement little capacity values with comparator

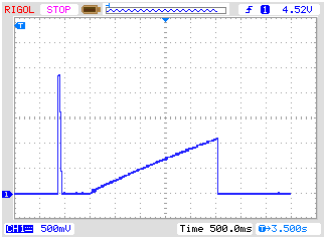
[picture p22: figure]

Figure 5.25: Charge and discharge of a 22µF Capacitor for measuring

In principle this technique of measurement can also be done with the 680Ω resistor, but because the ADC can’t be used if the comparator is working, I have no chance to monitor the load voltage until the comparator is stopped. If a undetected diode is parallel connected with the capacitor, the load current of the capacitor can be absorbed by the diode (threshold voltage) and the band-gap voltage will never be reached. The method taken in actual software for big capacitors in section 5.3.2 avoids this conceptual bug.

### 5.3.4 Measurement of the Equivalent Series Resistance ESR, first way

The series resistance ESR [8] is a good indicator for the aging of electrolytical capacitors for example. The figure 5.26 shows a equivalent circuit of a capacitor. The resistor Rp represents the leakage resistance of the capacitor, ESL the equivalent series inductivity and the resistance ESR represents the equivalent series resistance. If the measured capacitor has a capacity of more than 0.45µF, the tester will try to measure the series resistance too. For a capacity of more than 3.6µF the normal clock rate of 125kHz for the Analog-Digital converter is used. For lower capacities the higher clock rate of 500kHz is used to accelerate the measurement. The accuracy of the ADC results will be more worth by the higher clock rate, but this could be accepted by the higher ESR values of capacitors with lower capacity. Otherwise the measurement of ESR with this method is not possible for a capacity of less than 1.8µF at the normal clock rate of 125kHz.

Rp

C | ESR | ESL

Figure 5.26: Equivalent circuit of a capacitor

Strictly speaking the ESR of a capacitor depends on the operating frequency and temperature. Usually the value measured with sine wave-form signal of 100kHz is denoted in the data sheets. This measurement can not be done with the ATmega without external equipment. With the subsequent written method the measurement frequency with the standard ADC clock rate will be below 640 Hz with nearly rectangular signal. With 500kHz ADC clock rate the measurement frequency will be

2400 Hz. To get the value of the equivalent series resistance, the voltage of both connections will be measured during loading in one direction with the ADC internal reference voltage (1.1 V). After the measurement the load current will be switched off and the voltage of the capacitor is measured again without the current. If this voltage is below 3 mV, the sequence of measurement is repeated. The figure 5.27 shows the corresponding circuits.

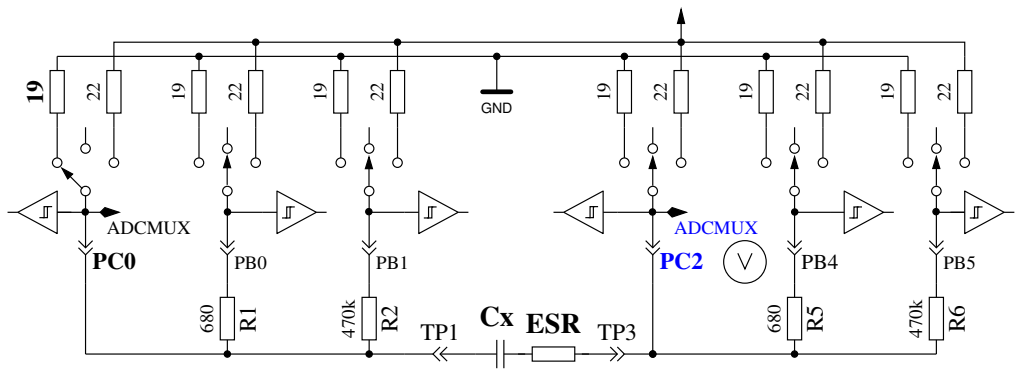
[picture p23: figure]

Figure 5.27: Circuit of the ESR measurements of a capacitor

The difference of capacitor voltages with and without current is proportional to the internal resistance of the capacitor. The expected voltage of this difference is so low, that one measurement can not result to a feasible result. Therefore after this the current will be switched to the opposite direction and the same measurement will be repeated. The whole measurement sequence will be done 128 times and the results of the voltage measurements will be added. So we have three sums of voltages, the voltage Ulp at the low side of the capacitor with current, the voltage Uhp at the high side of the capacitor with current and the voltage Uc of the high side of the capacitor without current. The sum of voltages at the low side of the capacitor represents the potential drop with the mean load current at the port output resistance Rport. The voltage difference of the high side and the low side of the capacitor represents the voltage of the capacitor with load current U diff = Uhp − Ulp. The difference Uesr = U diff −Uc should represent the voltage drop at the internal resistance of the capacitor with mean load current. We will get the resistance value with the relation of this voltage Uesr to the voltage Ulp, scaled with the known resistance value of the port output Rport. The scale factor is selected to get a resistance resolution of 0.01Ω: Resr =

Uesr·10·Rport
U lp The figure 5.28
shows a part of the voltage curve of a 4.2µF capacitor during the ESR measurement. To explain the influence of the ESR, a series 6.8Ω resistor is added to the capacitor. The little voltage break after loading the capacitor is interpreted by software to get the ESR. The greater voltage drop of the measurement to GND potential is caused by the port output resistance of about 20Ω. For this measurement a total ESR of 7.5Ω is reported by the tester, without the series 6.8Ω resistor a ESR of 0.56Ω is found. The figure 5.29 shows the same measurement with higher measurement frequency of a 2.2µF electrolytical capacitor with a ESR of 6.5Ω.

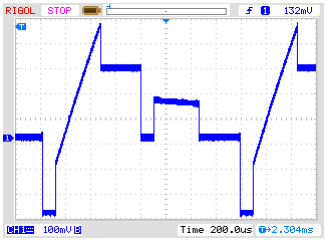
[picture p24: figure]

(a) measured one pin to GND | (b) measured pin to pin

Figure 5.28: Voltage curve of a 4.2µF capacitor during the ESR measurement

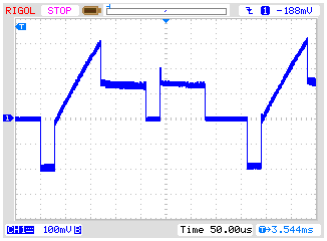
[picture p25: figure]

(a) measured one pin to GND | (b) measured pin to pin

Figure 5.29: Voltage curve of a 2.2µF capacitor during the ESR measurement

The accuracy of the ESR measurement is not very high by different reasons:

1. The voltage measurement at both pins of the capacitor can not be done at the same time, the only way is to do it in sequence. In the interim time between both measurements the load current has changed due to the charge of capacitor. The program tries to compensate this fact with a capacity dependent correction of the low side voltage.
2. The ADC takes the measurement voltage after 1.5 clock ticks after the start of conversion. The conversion beginns with the rising edge of the ADC-clock, if the start bit is set. If the charge current will be switched off to early, the ADC takes the wrong voltage for the measurement with current. If the charge current will be switched off to late, the capacitor will take more electric charge, than that of the corresponding measurement with load current. This will cause a too high voltage of the measurement without current. But it is difficult to switch off the current at the right time by software.
3. The port output resistance is used as a reference value by this measurement method, but this resistance value is not exacly known too.
4. The resolution of the ADC is not sufficient to get a resolution of resistance of 0.01Ω. To get the best avaiable resolution of ADC, the internal reference (1.1 V) is used for all measurements. The resolution deficit will be attenuated by accumulating a big number of single measurements too.
5. The switching of ports can not be exactly synchronized to the ADC clock with polling of conversion done.

Anyway the results seems to be practical, as shown with the following figure 5.30. The ESR values of the same part measured with the Transistortester vary more than the values measured with the LCR meter. The ESR values from the LCR meter are measured with a frequency of 1 kHz or are interpolated for little capacities to 2.4 kHz. You must respect the quality of all connection parts. The used cable connections can cause a higher measured resistance value. The plug connectors can also result a higher resistance value. The LCR meter has the advantage of the used Kelvin terminals. Only one capacitor with a capacity below 1µF was a 500nF ceramic type, all others were plastic film capacitors. The only electrolytical capacitor of the test series below 9µF was a 2.2µF capacitor.

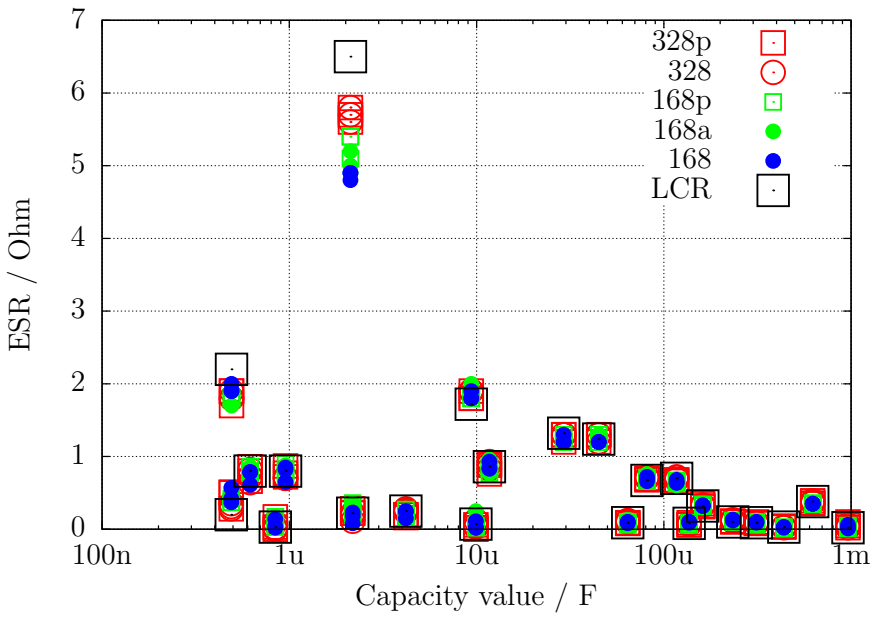
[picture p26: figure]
ESR / Ohm; Capacity value / F; LCR

Figure 5.30: ESR measurement results of 15 different ATmega
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

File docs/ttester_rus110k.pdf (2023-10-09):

# Тестер ЭРЭ с AVR микроконтроллером и минимумом дополнительных элементов Версия 1.10k

### Karl-Heinz K¨ubbeler

kh_kuebbeler@web.de

русский перевод Сергей Базыкин

11 апреля 2014 г.

# Оглавление

1 Характеристики | 5
2 Аппаратные средства | 8
3 Инструкция пользователя | 18
4 Конфигурирование Тестера | 24
5 Описание процедур измерения | 31

5.3.8 | Результаты измерения ёмкости конденсаторов | 68
5.3.9 | Автоматическая калибровка при измерении конденсаторов | 72
5.4 Измерение индуктивностей | | 76
5.4.1 | Результаты измерений индуктивности | 77
5.5 Функция самопроверки | 78
5.5.1 Некоторые результаты функции самопроверки | 82
5.6 Измерение частоты | 86
6 Генератор сигналов | 88
6.1 Генератор частоты | 88
6.2 Широтно-импульсный генератор | 88
7 Известные ошибки и нерешенные проблемы | 89
8 Специальные модули программного обеспечения | 90
9 Список текущих дел и новые идеи | 91

## Вступление

### Основные мотивы

Каждый радиолюбитель знает следующую задачу: Вы выпаяли транзистор из печатной платы или достали один из коробки. Если на нем есть маркировка, и у Вас уже есть паспорт или Вы можете получить документацию об этом элементе, то все в порядке. Но если документация отсутствует, то Вы понятия не имеете, что это за элемент. Традиционный подход измерения всех параметров сложный и трудоемкий. Элемент может быть N-P-N, P-N-P, N или P-канальным MOSFET транзистором и т.д. Идея Markus F. заключалась в том, чтобы переложить ручную работу на AVR микроконтроллер.

### Начало моей работы над проектом

Моя работа с программным обеспечением Тестера от Markus F.[1] началось, потому что у меня были проблемы с моим программатором. Я купил печатную плату и элементы, но не смог запрограммировать EEprom ATmega8 с драйвером Windows без сообщения об ошибке. Поэтому я взял программное обеспечение от Markus F. и изменил все обращения из памяти EEprom к Flash памяти. Анализируя программное обеспечение для того, чтобы сохранить память в других местах программы, у меня появилась идея изменить результат функции ReadADC из единиц АЦП на милливольты (mV ). Размерность в mV необходима для любого вывода значения напряжения. Если функция ReadADC возвращает значения непосредственно в mV , я могу сохранять преобразования для каждого выходного значения. Размерность в mV можно получить, если суммировать результаты 22 показаний АЦП, сумму умножить на 2 и разделить на
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

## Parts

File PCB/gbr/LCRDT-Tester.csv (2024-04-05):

ID | Bezeichner | Footprint | Stückzahl | Bezeichnung | Anbieter und Referenz
1 | J1 | PinSocket_1x03_P2.54mm_Vertical | 1 | Test
2 | R6,R4,R2 | R_Axial_DIN0204_L3.6mm_D1.6mm_P7.62mm_Horizontal | 3 | 10K
3 | R1,R3,R5 | R_Axial_DIN0204_L3.6mm_D1.6mm_P7.62mm_Horizontal | 3 | 330
4 | C1 | C_Disc_D5.0mm_W2.5mm_P5.00mm | 1 | 100n
5 | A1 | Arduino_Nano_WithMountingHoles | 1 | Arduino_Nano_v3.x
6 | Start | SW_PUSH_6mm_H4.3mm | 1 | SW_Push
7 | J2 | PinSocket_1x04_P2.54mm_Vertical | 1 | Disp
8 | Reset | SW_PUSH_1P1T_6x3.5mm_H4.3_APEM_MJTP1243 | 1 | SW_Push

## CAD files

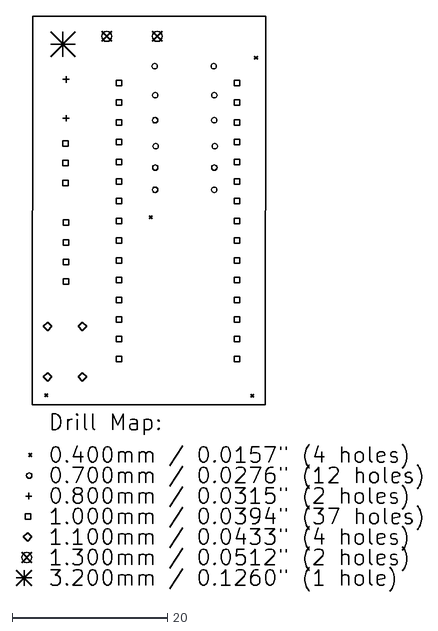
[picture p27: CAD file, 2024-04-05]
PCB/gbr/LCRDT-Tester-PTH-drl_map.dxf
52.2 x 74.1

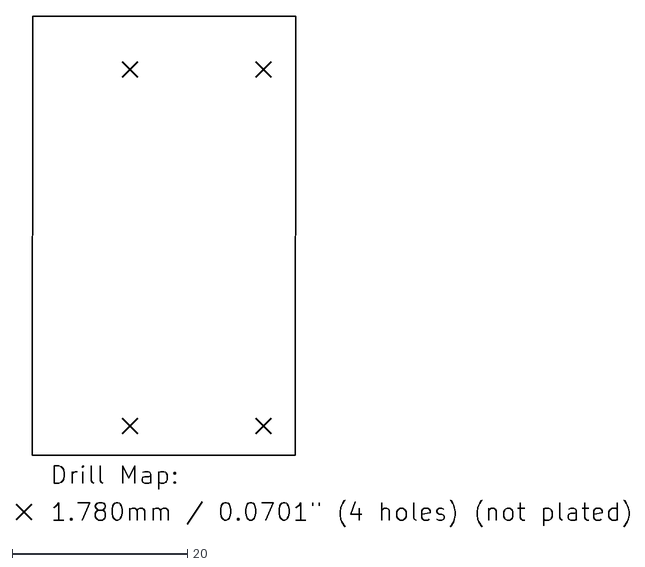
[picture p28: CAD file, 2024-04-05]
PCB/gbr/LCRDT-Tester-NPTH-drl_map.dxf
69.9 x 58.2

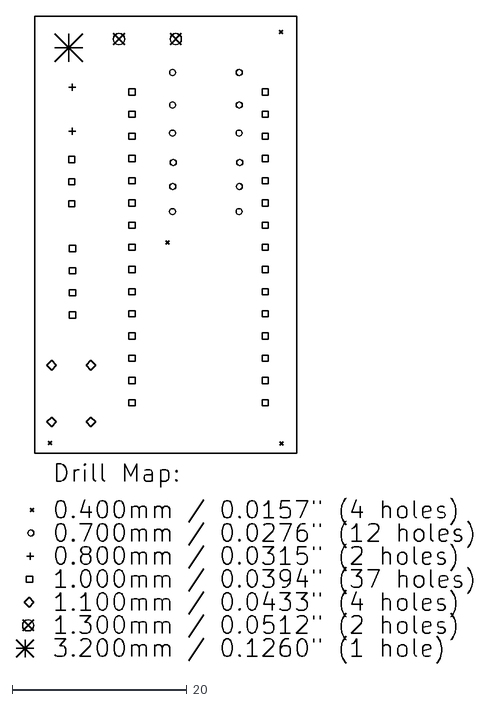
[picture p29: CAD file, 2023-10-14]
PCB/gbr/LCRDT-Tester-PTH-drl-drl_map.dxf
52.2 x 74.1

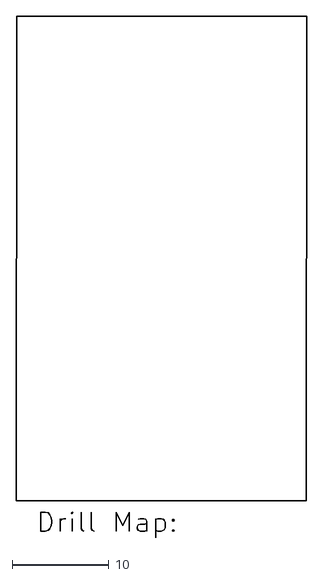
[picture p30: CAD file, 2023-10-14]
PCB/gbr/LCRDT-Tester-NPTH-drl-drl_map.dxf
30.0 x 53.9

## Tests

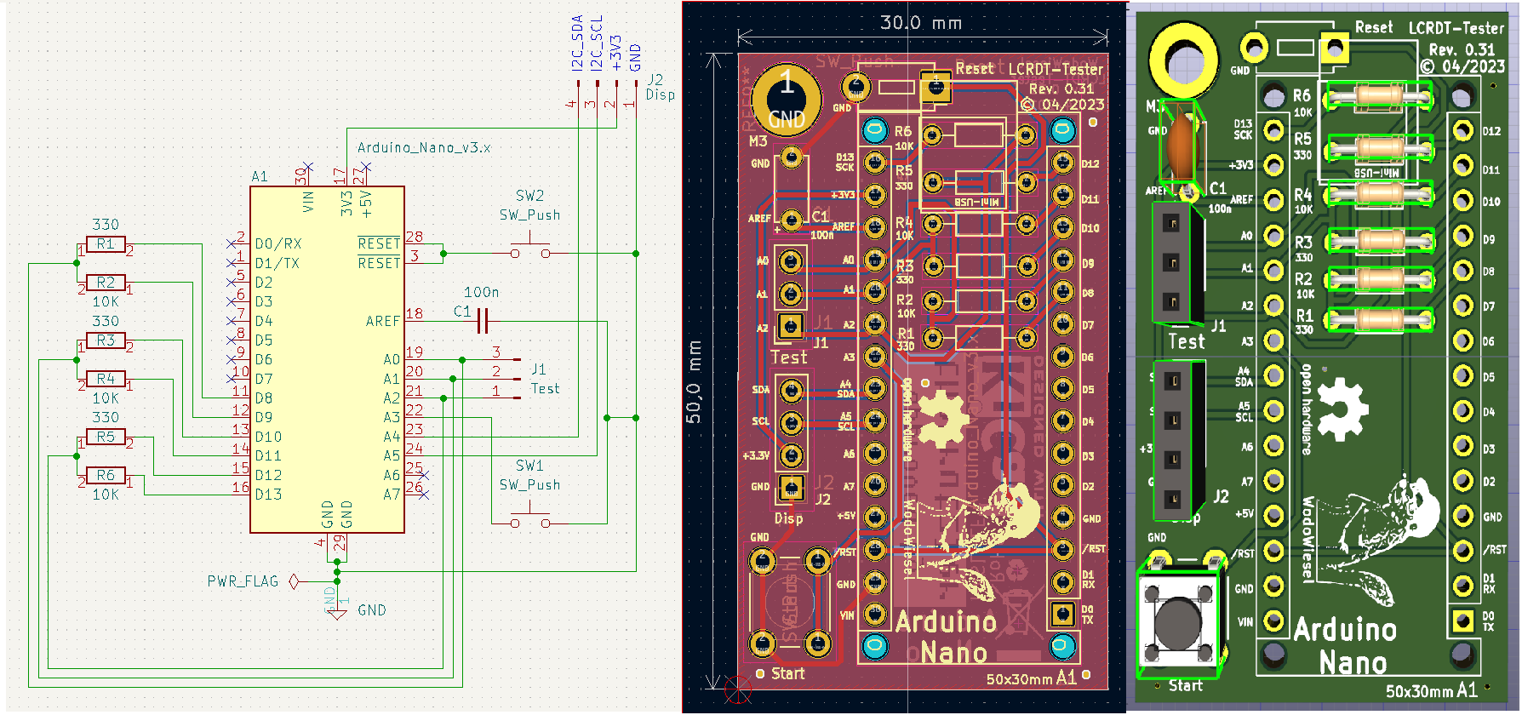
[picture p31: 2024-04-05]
docs/PCB-layout-Wodowiesel-LCRDT-tester-schematics.png

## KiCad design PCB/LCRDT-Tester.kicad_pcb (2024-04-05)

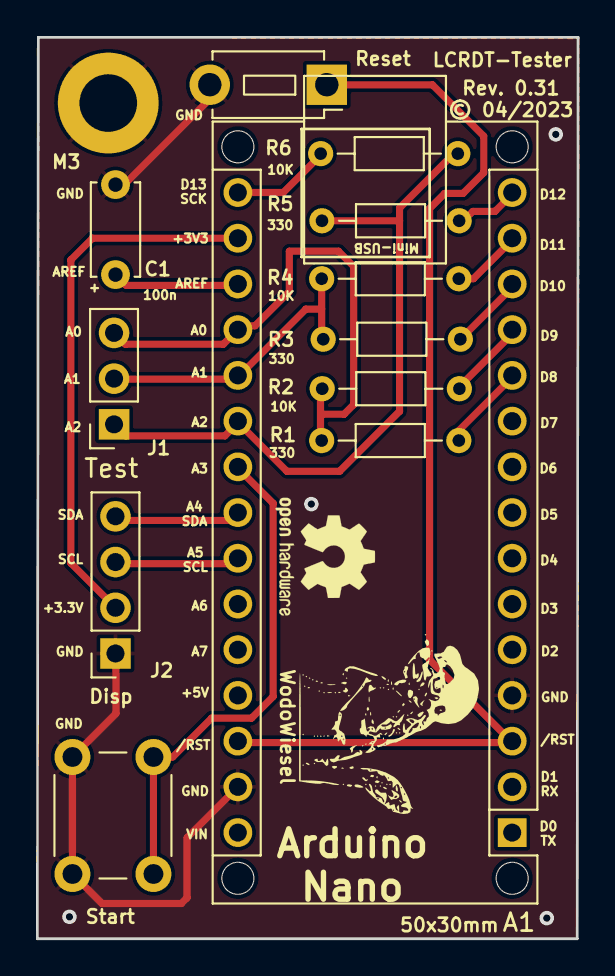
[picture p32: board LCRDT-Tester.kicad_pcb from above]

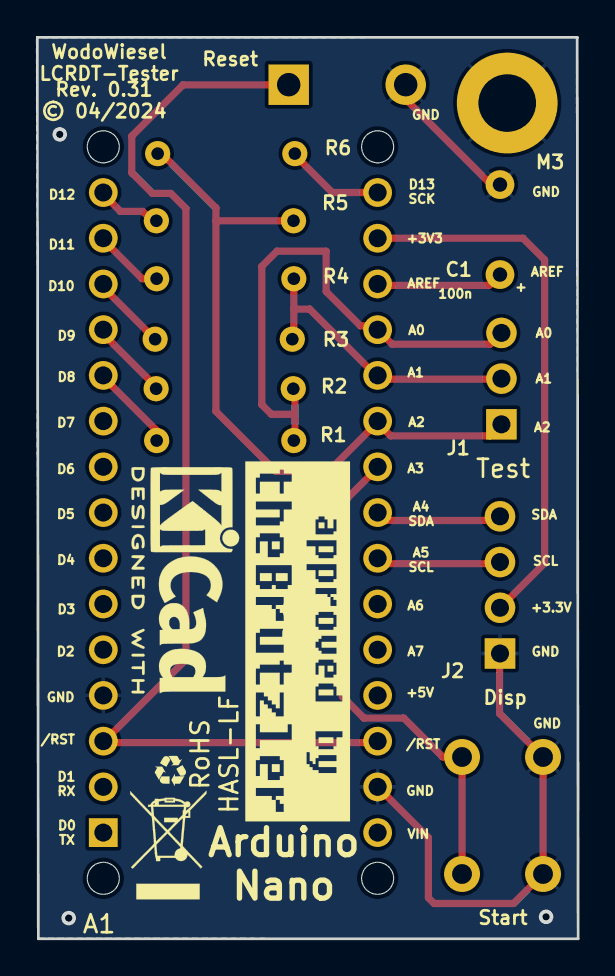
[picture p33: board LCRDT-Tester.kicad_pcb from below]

Board: 2 copper layers, 30.0 x 50.1 mm, 18 parts (4 on the bottom side), 16 nets.

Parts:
A1: Arduino_Nano_v3.x; Arduino_Nano_WithMountingHoles
C1: 100n; C_Disc_D5.0mm_W2.5mm_P5.00mm
G3*: LOGO; recycling-symbol-kicad
G6**: LOGO; approved_theBrutzler
G21: LOGO; wiesel-kicad-back-white
J1: Test; PinSocket_1x03_P2.54mm_Vertical
J2: Disp; PinSocket_1x04_P2.54mm_Vertical
R1, R3, R5: 330; R_Axial_DIN0204_L3.6mm_D1.6mm_P7.62mm_Horizontal
R2, R4, R6: 10K; R_Axial_DIN0204_L3.6mm_D1.6mm_P7.62mm_Horizontal
REF7**: WEEE-Logo_4.2x6mm_SilkScreen
REF8**: KiCad-Logo2_5mm_SilkScreen
REF9**: MountingHole_3.2mm_M3_DIN965_Pad
Reset: SW_Push; SW_PUSH_1P1T_6x3.5mm_H4.3_APEM_MJTP1243
Start: SW_Push; SW_PUSH_6mm_H4.3mm

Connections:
GND: A1.4 (GND), A1.29 (GND), C1.2, J2.1, REF9**.1, Reset.2, Start.2
unnamed: A1.17 (3V3), J2.2
unnamed: A1.19 (A0), J1.3, R1.1, R2.2
unnamed: A1.20 (A1), J1.2, R3.1, R4.2
unnamed: A1.21 (A2), J1.1, R5.1, R6.2
unnamed: A1.22 (A3), Start.1
unnamed: A1.23 (A4), J2.4
unnamed: A1.24 (A5), J2.3
unnamed: A1.18 (AREF), C1.1
unnamed: A1.11 (D8), R1.2
unnamed: A1.12 (D9), R2.1
unnamed: A1.13 (D10), R3.2
unnamed: A1.14 (D11), R4.1
unnamed: A1.15 (D12), R5.2
unnamed: A1.16 (D13), R6.1
unnamed: A1.3 (~RESET), A1.28 (~RESET), Reset.1

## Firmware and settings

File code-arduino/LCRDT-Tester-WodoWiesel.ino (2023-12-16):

// wodowiesel 12/12/2023
// LCRDT-Tester for Arduino (version 1.12)
// https://github.com/wodowiesel/LCRDT-Tester
// original sources:
// https://arduino.ru/forum/proekty/transistor-tester-arduino
// https://github.com/vlad-gheorghe/ardutester
// based  on PDF: Karl-Heinz Kubbeler (version 1.08k, 2013/ 1.10, 2014)

#include <avr/io.h>
#include <util/delay.h>
#include <avr/sleep.h>
#include <stdlib.h>
#include <string.h>
#include <avr/eeprom.h>
#include <avr/pgmspace.h>
#include <avr/wdt.h>
#include <avr/interrupt.h>
#include <math.h>
#include <stdint.h>
#include <avr/power.h>

//#define LCD1602 // I2C
//#define LCD_I2C
//#define NOK5110 // SPI
//#define OLED096 // SPI SSD1306
#define OLED_I2C  // SSD1306

#ifdef LCD_I2C
  #ifndef LCD1602
    #define LCD1602
  #endif
#endif

#ifdef OLED_I2C
  #ifndef OLED096
    #define OLED096
  #endif
#endif

#ifdef LCD1602
  #ifdef LCD_I2C
    #include <Wire.h> 
    #include <LiquidCrystal_I2C.h>
  #else
    #include <LiquidCrystal.h>
  #endif
#endif

#ifdef NOK5110
  #include <SPI.h>
  #include <Adafruit_GFX.h>
  #include <Adafruit_PCD8544.h>
#endif

#ifdef OLED096
  #include <SPI.h>
  #include <Wire.h>
  #include <Adafruit_GFX.h>
  #include <Adafruit_SSD1306.h>
#endif

// ******** config options for your Semiconductor tester
// Every changing of this Makefile will result in new compiling the whole
// programs, if you call make or make upload.

#define MCU atmega328p
#define F_CPU 16000000UL

// Select your language:
// Available languages are: LANG_ENGLISH, LANG_GERMAN, LANG_POLISH, LANG_CZECH, LANG_SLOVAK, LANG_SLOVENE,
//                          LANG_DUTCH, LANG_BRASIL, LANG_RUSSIAN, LANG_UKRAINIAN
#define LANG_ENGLISH

// The LCD_CYRILLIC option is necessary, if you have a display with cyrillic characterset.
// This lcd-display don't have a character for Ohm and for u (micro).
// Russian language requires a LCD controller with russian characterset and option LCD_CYRILLIC!
//#define LCD_CYRILLIC

// The LCD_DOGM option must be set for support of the DOG-M type of LCD modules with ST7036 controller.
// For this LCD type the contrast must be set with software command.
//#define LCD_DOGM

// Option STRIP_GRID_BOARD selects different board-layout, do not set for standard board!
// The connection of LCD is totally different for both versions.
//#define STRIP_GRID_BOARD

// The WITH_SELFTEST option enables selftest function (only for mega168 or mega328).
//#define WITH_SELFTEST

// AUTO_CAL will enable the autocalibration of zero offset of capacity measurement and
// also the port output resistance values will be find out in SELFTEST section.
// With a external capacitor a additionally correction of reference voltage is figured out for 
// low capacity measurement and also for the AUTOSCALE_ADC measurement.
// The AUTO_CAL option is only selectable for mega168 and mega328.
//#define AUTO_CAL

// FREQUENCY_50HZ enables a 50 Hz frequency generator for up to one minute at the end of selftests.
//#define FREQUENCY_50HZ

// The WITH_AUTO_REF option enables reading of internal REF-voltage to get factors for the Capacity measuring.
#define WITH_AUTO_REF // nano v3 -> 1.1V
// REF_C_KORR corrects the reference Voltage for capacity measurement (<40uF) and has mV units.
// Greater values gives lower capacity results.
#define REF_C_KORR 12
// REF_L_KORR corrects the reference Voltage for inductance measurement and has mV units.
#define REF_L_KORR 40
// C_H_KORR defines a correction of 0.1% units for big capacitor measurement.
// Positive values will reduce measurement results.
#define C_H_KORR 0

// The WITH_UART option enables the software UART (TTL level output at Pin PC3, 26).
// If the option is deselected, PC3 can be used as external voltage input with a
// 10:1 resistor divider.
//#define WITH_UART

// The CAP_EMPTY_LEVEL  defines the empty voltage level for capacitors in mV.
// Choose a higher value, if your Tester reports "Cell!" by unloading capacitors.
#define CAP_EMPTY_LEVEL 4

// The AUTOSCALE_ADC option enables the autoscale ADC (ADC use VCC and Bandgap Ref).
#define AUTOSCALE_ADC
#define REF_R_KORR 3

// The ESR_ZERO value define the zero value of ESR measurement (units = 0.01 Ohm).
//#define ESR_ZERO 29
#define ESR_ZERO 20

// NO_AREF_CAP tells your Software, that you have no Capacitor installed at pin AREF (21)-> nano pin 18
// This enables a shorter wait-time for AUTOSCALE_ADC function.
// A capacitor with 1 nF can be used with the option NO_AREF_CAP set.
// Connect CAP over AREF to GND
//#define NO_AREF_CAP // =0
//#define AREF_CAP 100

// The OP_MHZ option tells the software the Operating Frequency of your ATmega.
// OP_MHZ 16

// Restart from sleep mode will be delayed for 16384 clock tics with crystal mode.
// Operation with the internal RC-Generator or external clock will delay the restart by only 6 clock tics.
// You must specify this with "#define RESTART_DELAY_TICS=6", if you don't use the crystal mode.
//#define RESTART_DELAY_TICS 6

// The USE_EEPROM option specify where you wish to locate fix text and tables.
// If USE_EEPROM is unset, program memory (flash) is taken for fix text and tables.
//#define USE_EEPROM

// Setting EBC_STYPE will select the old style to present the order of Transistor connection (EBC=...).
// Omitting the option will select the 123=... style.  Every point is replaced by a character identifying 
// type of connected transistor pin (B=Base, E=Emitter, C=Collector, G=Gate, S=Source, D=Drain).
// If you select EBC_STYLE=321 , the style will be 321=... , the inverted order to the 123=... style.
//#define EBC_STYLE
//#define EBC_STYLE 321

// Setting of NO_NANO avoids the use of n as prefix for Farad (nF), the mikro prefix is used insted (uF).
//#define NO_NANO

// The PULLUP_DISABLE option disables the pull-up Resistors of IO-Ports.
// To use this option a external pull-up Resistor (10k to 30k)
// from Pin 13 (?) to VCC must be installed!
#define PULLUP_DISABLE

// The ANZ_MESS option specifies, how often an ADC value is read and accumulated.
// Possible values of ANZ_MESS are 5 to 200.
#define ANZ_MESS 25

// The POWER_OFF option enables the power off function, otherwise loop measurements infinitely
// until power is disconnected with a ON/OFF switch (#define POWER_OFF).
// If you have the tester without the power off transistors, you can deselect POWER_OFF .
// If you have NOT selected the POWER_OFF option with the transistors installed,
// you can stop measuring by holding the key several seconds after a result is
// displayed. After releasing the key, the tester will be shut off by timeout.
// Otherwise you can also specify, after how many measurements without found part
// the tester will shut down (#define POWER_OFF=5).
// The tester will also shut down with found part,
// but successfull measurements are allowed double of the specified number.
// You can specify up to 255 empty measurements (#define POWER_OFF=255).
//#define POWER_OFF 5
//#define POWER_OFF

// Option BAT_CHECK enables the Battery Voltage Check, otherwise the SW Version is displayed instead of Bat.
// BAT_CHECK should be set for battery powered tester version.
//#define BAT_CHECK

// The BAT_OUT option enables Battery Voltage Output on LCD (if BAT_CHECK is selected).
// If your 9V supply has a diode installed, use the BAT_OUT=600 form to specify the
// threshold voltage of your diode to adjust the output value.
// This threshold level is added to LCD-output and does not affect the voltage checking levels.
//#define BAT_OUT 150

// To adjust the warning-level and poor-level of battery check to the capability of a
// low drop voltage regulator, you can specify the Option BAT_POOR=5400 .
// The unit for this option value is 1mV , 5400 means a poor level of 5.4V.
// The warning level is 0.8V higher than the specified poor level (>5.3V).
// The warning level is 0.4V higher than the specified poor level (>2.9V, <=5.3V).
// The warning level is 0.2V higher than the specified poor level (>1.3V, <=2.9V).
// The warning level is 0.1V higher than the specified poor level (<=1.3V).
// Setting the poor level to low values is not recommended for rechargeable Batteries,
// because this increase the danger for deep discharge!!
#define BAT_POOR 6400

// The sleep mode of the ATmega168 or ATmega328 is normally used by the software to save current.
// You can inhibit this with the option INHIBIT_SLEEP_MODE .
//#define INHIBIT_SLEEP_MODE

// ******** end of selectable options

/* -=- -=- -=- -=- -=- -=- -=- -=- -=- -=- -=- -=- -=- -=- -=- -=- -=- -=- -=- -=- -=- -=- -=- -=- -=- -=- -=- -=- */

// ########  Configuration

#ifndef ADC_PORT // debug
/*
#define DebugOut 3    // if set, output of voltages of resistor measurements in row 2,3,4
#define DebugOut 4    // if set, output of voltages of Diode measurement in row 3+4
#define DebugOut 5    // if set, output of Transistor checks in row 2+3
#define DebugOut 10   // if set, output of capacity measurements (ReadCapacity) in row 3+4 
*/
/*
  Port, that is directly connected to the probes.
  This Port must have an ADC-Input  (ATmega8:  PORTC).
  The lower pins of this Port must be used for measurements.
  Please don't change the definitions of TP1, TP2 and TP3!
  The TPREF pin can be connected with a 2.5V precision voltage reference
  The TPext can be used with a 10:1 resistor divider as external voltage probe up to 50V
*/

#define ADC_PORT PORTC
#define ADC_DDR DDRC
#define ADC_PIN PINC
#define TP1 0
#define TP2 1
#define TP3 2
#define TPext 3
// Port pin for 2.5V precision reference used for VCC check (optional)
#define TPREF 4
// Port pin for Battery voltage measuring
#define TPBAT 5

/*
  exact values of used resistors (Ohm).
  The standard value for R_L is 680 Ohm, for R_H 470kOhm.

  To calibrate your tester the resistor-values can be adjusted:
*/
//#define R_L_VAL 680 0          // standard value 680 Ohm, multiplied by 10 for 0.1 Ohm resolution
#define R_L_VAL 3300        // this will define a 330 Ohm
//#define R_H_VAL 470 00         // standard value 470 000 Ohm, multiplied by 10, divided by 100 
#define R_H_VAL 1000       // this will define a 10 000 Ohm, multiplied by 10 (10 000  0), divided by 100 (10 00)

#define R_DDR DDRB
#define R_PORT PORTB

/*
  Port for the Test resistors
  The Resistors must be connected to the lower 6 Pins of the Port in following sequence:
  RLx = 680  resistor for Test-Pin x
  RHx = 470k resistor for Test-Pin x

  RL1 an Pin 0
  RH1 an Pin 1
  RL2 an Pin 2
  RH2 an Pin 3
  RL3 an Pin 4
  RH3 an Pin 5
*/

#define ON_DDR DDRD
#define ON_PORT PORTD
#define ON_PIN_REG PIND
#define ON_PIN 18               // Pin, must be switched to high to switch power on (aref?)

#ifdef STRIP_GRID_BOARD
// Strip Grid board version
  #define RST_PIN 0             // Pin, is switched to low, if push button is pressed
#else
// normal layout version
  //#define RST_PIN 17            // Pin, is switched to low, if push button is pressed
  #define RST_PIN 28
  //#define RST_PINX 3
#endif

// Port(s)/ Pins for LCD

#ifdef STRIP_GRID_BOARD
  // special Layout for strip grid board
  #define HW_LCD_EN_PORT         PORTD
  #define HW_LCD_EN_PIN          5

  #define HW_LCD_RS_PORT         PORTD
  #define HW_LCD_RS_PIN          7

  #define HW_LCD_B4_PORT         PORTD
  #define HW_LCD_B4_PIN          4
  #define HW_LCD_B5_PORT         PORTD
  #define HW_LCD_B5_PIN          3
  #define HW_LCD_B6_PORT         PORTD
  #define HW_LCD_B6_PIN          2
  #define HW_LCD_B7_PORT         PORTD
  #define HW_LCD_B7_PIN          1
#else
  // normal Layout
  #define HW_LCD_EN_PORT         PORTD
  #define HW_LCD_EN_PIN          6

  #define HW_LCD_RS_PORT         PORTD
  #define HW_LCD_RS_PIN          7

  #define HW_LCD_B4_PORT         PORTD
  #define HW_LCD_B4_PIN          5
  #define HW_LCD_B5_PORT         PORTD
  #define HW_LCD_B5_PIN          4
  #define HW_LCD_B6_PORT         PORTD
  #define HW_LCD_B6_PIN          3
  #define HW_LCD_B7_PORT         PORTD
  #define HW_LCD_B7_PIN          2
#endif

// U_VCC defines the VCC Voltage of the ATmega in mV units

#define U_VCC 5000
// integer factors are used to change the ADC-value to mV resolution in ReadADC !

// With the option NO_CAP_HOLD_TIME you specify, that capacitor loaded with 680 Ohm resistor will not
// be tested to hold the voltage same time as load time.
// Otherwise (without this option) the voltage drop during load time is compensated to avoid displaying
// too much capacity for capacitors with internal parallel resistance.
// #define NO_CAP_HOLD_TIME

// U_SCALE can be set to 4 for better resolution of ReadADC function for resistor measurement
#define U_SCALE 4

// R_ANZ_MESS can be set to a higher number of measurements (up to 200) for resistor measurement
#define R_ANZ_MESS 190

// Watchdog
//#define WDT_enabled
/*
  If you remove the "#define WDT_enabled" , the Watchdog will not be activated.
  This is only for Test or debugging usefull.
  For normal operation please activate the Watchdog !
*/

// ########  End of configuration 

#if R_ANZ_MESS < ANZ_MESS
  #undef R_ANZ_MESS
  #define R_ANZ_MESS ANZ_MESS
#endif
#if U_SCALE < 0
  // limit U_SCALE
  #undef U_SCALE
  #define U_SCALE 1
#endif
#if U_SCALE > 4
  // limit U_SCALE
  #undef U_SCALE
  #define U_SCALE 4
#endif
#ifndef REF_L_KORR
  #define REF_L_KORR 50
#endif
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
void loop()
{
  // Entry: if start key is pressed before shut down
start:

  #ifdef NOK5110
    lcd.display();
  #endif

  #ifdef OLED096
    display.display();
  #endif

  TestKey = 1;
  while(TestKey) {
    TestKey = digitalRead(TestKeyPin);
    delay(100);
  }
  while(!TestKey) {
    TestKey = digitalRead(TestKeyPin);
    delay(100);
  }
  
  #define RESETPIN 3 // || 26
  int ResetKey = 1;
  /*
  while(ResetKey) {
  //loop
    digitalWrite(RESETPIN, LOW);
  } */
  
  lcd_clear();
  delay(100);

  PartFound = PART_NONE;  // no part found
  NumOfDiodes = 0;    // Number of diodes = 0
  PartReady = 0;
  PartMode = 0;
  WithReference = 0;    // no precision reference voltage
  ADC_DDR = TXD_MSK;    // activate Software-UART 
  ResistorsFound = 0;   // no resistors found
  cap.ca = 0;
  cap.cb = 0;

  #ifdef WITH_UART
    uart_newline();   // start of new measurement
  #endif

  ADCconfig.RefFlag = 0;
  Calibrate_UR();   // get Ref Voltages and Pin resistance
  lcd_line1();    // 1 row
  
  ADCconfig.U_Bandgap = ADC_internal_reference;  // set internal reference voltage for ADC

  #ifdef BAT_CHECK
    // Battery check is selected
    ReadADC(TPBAT);     // Dummy-Readout
    trans.uBE[0] = W5msReadADC(TPBAT);  // with 5V reference
    lcd_fix_string(Bat_str);    // output: "Bat. "

    #ifdef BAT_OUT
      // display Battery voltage
      // The divisor to get the voltage in 0.01V units is ((10*33)/133) witch is about 2.4812
      // A good result can be get with multiply by 4 and divide by 10 (about 0.75%).
      //cap.cval = (trans.uBE[0]*4)/10+((BAT_OUT+5)/10); // usually output only 2 digits
      //DisplayValue(cap.cval,-2,'V',2);    // Display 2 Digits of this 10mV units
      cap.cval = (trans.uBE[0]*4)+BAT_OUT;    // usually output only 2 digits
      DisplayValue(cap.cval,-3,'V',2);      // Display 2 Digits of this 10mV units
      lcd_space();
    #endif

    #if (BAT_POOR > 12000)
      #warning "Battery POOR level is set very high!"
    #endif
    #if (BAT_POOR < 2500)
      #warning "Battery POOR level is set very low!"
    #endif

    #if (BAT_POOR > 5300)
      // use .8 V difference to Warn-Level
      #define WARN_LEVEL (((unsigned long)(BAT_POOR+800)*(unsigned long)33)/133)
    #elif (BAT_POOR > 3249)
      // less than 5.4 V only .4V difference to Warn-Level
      #define WARN_LEVEL (((unsigned long)(BAT_POOR+400)*(unsigned long)33)/133)
    #elif (BAT_POOR > 1299)
      // less than 2.9 V only .2V difference to Warn-Level
      #define WARN_LEVEL (((unsigned long)(BAT_POOR+200)*(unsigned long)33)/133)
    #else
      // less than 1.3 V only .1V difference to Warn-Level
      #define WARN_LEVEL (((unsigned long)(BAT_POOR+100)*(unsigned long)33)/133)
    #endif

    #define POOR_LEVEL (((unsigned long)(BAT_POOR)*(unsigned long)33)/133)

    // check the battery voltage
    if (trans.uBE[0] <  WARN_LEVEL) {

      // Vcc < 7,3V; show Warning 
      if(trans.uBE[0] < POOR_LEVEL) { 
        // Vcc <6,3V; no proper operation is possible
        lcd_fix_string(BatEmpty); // Battery empty!
        wait_about2s();
        PORTD = 0;      // switch power off
        return;
      }

      lcd_fix_string(BatWeak);    // Battery weak
    } else {                            // Battery-voltage OK
      lcd_fix_string(OK_str);     // "OK"
    }

  #else
    lcd_fix2_string(VERSION_str); // if no Battery check, Version .. in row 1
  #endif

  #ifdef WDT_enabled
    //wdt_enable(WDTO_2S);    // Watchdog on
  #endif

  //wait_about1s();     // add more time for reading batterie voltage

  // begin tests

  #ifdef AUTO_RH
    RefVoltage();     // compute RHmultip = f(reference voltage)
  #endif

  #if FLASHEND > 0x1fff
    if (WithReference) {
      // 2.5V precision reference is checked OK
      if ((mess_count == 0) && (empty_count == 0)) {
        // display VCC= only first time
        lcd_line2();
        lcd_fix_string(VCC_str);      // VCC=
        DisplayValue(ADCconfig.U_AVCC,-3,'V',3);  // Display 3 Digits of this mV units
        //lcd_space();
        //DisplayValue(RRpinMI,-1,LCD_CHAR_OMEGA,4);
        wait_about1s();
      }
    }
  #endif

  #ifdef WITH_VEXT
    // show the external voltage
    while (!(ON_PIN_REG & (1<<RST_PIN))) {
      lcd_line2();
      lcd_clear_line();
      lcd_line2();
      lcd_fix_string(Vext_str);     // Vext=
      ADC_DDR = 0;        // deactivate Software-UART
      trans.uBE[1] = W5msReadADC(TPext);  // read external voltage 
      ADC_DDR = TXD_MSK;      // activate Software-UART 

      #ifdef WITH_UART
        uart_newline();   // start of new measurement
      #endif

      DisplayValue(trans.uBE[1]*10,-3,'V',3); // Display 3 Digits of this mV units
      wait_about300ms();
    }
  #endif

  lcd_line2();      // LCD position row 2, column 1
  lcd_fix_string(TestRunning);  // String: testing...

  #ifndef DebugOut
    lcd_line2();    // LCD position row 2, column 1
  #endif

  #ifdef NOK5110
    lcd.display();
  #endif

  #ifdef OLED096
    display.display();
    display.setCursor(0,0);
  #endif

  delay(5);

  EntladePins();    // discharge all capacitors!

  if(PartFound == PART_CELL) {
    lcd_clear();
    lcd_fix_string(Cell_str); // display "Cell!"
    goto end2;
  }

  #ifdef CHECK_CALL
    AutoCheck();    // check, if selftest should be done
  #endif
     
  // check all 6 combinations for the 3 pins 
  //       High  Low  Tri
  CheckPins(TP1, TP2, TP3);
  CheckPins(TP2, TP1, TP3);
  CheckPins(TP1, TP3, TP2);
  CheckPins(TP3, TP1, TP2);
  CheckPins(TP2, TP3, TP1);
  CheckPins(TP3, TP2, TP1);
  
  // separate check if is is a capacitor
  if(((PartFound == PART_NONE) || (PartFound == PART_RESISTOR) || (PartFound == PART_DIODE)) ) {
    EntladePins();    // discharge capacities
    // measurement of capacities in all 3 combinations
    cap.cval_max = 0;   // set max to zero
    cap.cpre_max = -12;   // set max to pF unit

    ReadCapacity(TP3, TP1);
    ReadCapacity(TP3, TP2);
    ReadCapacity(TP2, TP1);

    #if FLASHEND > 0x1fff
      ReadInductance();   // measure inductance
    #endif
  }

  // All checks are done, output result to display
  lcd_clear();

  if(PartFound == PART_DIODE) {
    if(NumOfDiodes == 1) {    // single Diode
      //lcd_fix_string(Diode);    // "Diode: "

      #if FLASHEND > 0x1fff
        // enough memory to sort the pins

        #if EBC_STYLE == 321
          // the higher test pin number is left side
          if (diodes[0].Anode > diodes[0].Cathode) {
            lcd_testpin(diodes[0].Anode);
            lcd_fix_string(AnKat);          // "->|-"
            lcd_testpin(diodes[0].Cathode);
          } else {
            lcd_testpin(diodes[0].Cathode);
            lcd_fix_string(KatAn);          // "-|<-"
            lcd_testpin(diodes[0].Anode);
          }
        #else
          // the higher test pin number is right side
          if (diodes[0].Anode < diodes[0].Cathode) {
            lcd_testpin(diodes[0].Anode);
            lcd_fix_string(AnKat);          // "->|-"
            lcd_testpin(diodes[0].Cathode);
          } else {
            lcd_testpin(diodes[0].Cathode);
            lcd_fix_string(KatAn);          // "-|<-"
            lcd_testpin(diodes[0].Anode);
          }
        #endif

      #else
        // too less memory to sort the pins
        lcd_testpin(diodes[0].Anode);
        lcd_fix_string(AnKat);          // "->|-"
        lcd_testpin(diodes[0].Cathode);
      #endif

      #if FLASHEND > 0x1fff
        GetIr(diodes[0].Cathode,diodes[0].Anode);
      #endif

      UfOutput(0x70);

      #if defined(NOK5110) || defined(OLED096)
        lcd_line3();
      #endif

      // load current of capacity is (5V-1.1V)/(470000 Ohm) = 8298nA
      lcd_fix_string(GateCap_str);      // "C="
      ReadCapacity(diodes[0].Cathode,diodes[0].Anode);  // Capacity opposite flow direction
      DisplayValue(cap.cval,cap.cpre,'F',3);
      goto end;

    } else if(NumOfDiodes == 2) {   // double diode
      lcd_data('2');
      lcd_fix_string(Diodes);   // "diodes "

      if(diodes[0].Anode == diodes[1].Anode) { //Common Anode
        lcd_testpin(diodes[0].Cathode);
        lcd_fix_string(KatAn);          // "-|<-"
        lcd_testpin(diodes[0].Anode);
        lcd_fix_string(AnKat);          // "->|-"
        lcd_testpin(diodes[1].Cathode);
        UfOutput(0x01);
        goto end;

      } else if(diodes[0].Cathode == diodes[1].Cathode) { //Common Cathode
        lcd_testpin(diodes[0].Anode);
        lcd_fix_string(AnKat);          // "->|-"
        lcd_testpin(diodes[0].Cathode);
        lcd_fix_string(KatAn);          // "-|<-"
        lcd_testpin(diodes[1].Anode);
        UfOutput(0x01);
        goto end;
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

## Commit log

2023-09-16 init pcb/schemetics/docs/code
    init pcb/schemetics/docs/code
    [LCRD-TesterX.kicad_pcb, LCRD-TesterX.kicad_sch]
2023-10-09 -added m3 mounting hole -added start button -more compact design -added logos -added 3d arduino shapes wrl -updated docs & readme -updated code
    [LCRD-TesterX.kicad_pcb, LCRDT-Tester.kicad_pcb, LCRDT-Tester.kicad_sch]
2023-10-11 -adapt code to custom resistor val -activate autoscale -changed rst pin nr -deactivate rus charset lcd (optional) using english
2023-10-14 upload gerber, drill and different export files
    [GB-Dumper.dsn, GB-Dumper.step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]
2023-10-21 fix typo
    [LCRDT-Tester.kicad_pcb]

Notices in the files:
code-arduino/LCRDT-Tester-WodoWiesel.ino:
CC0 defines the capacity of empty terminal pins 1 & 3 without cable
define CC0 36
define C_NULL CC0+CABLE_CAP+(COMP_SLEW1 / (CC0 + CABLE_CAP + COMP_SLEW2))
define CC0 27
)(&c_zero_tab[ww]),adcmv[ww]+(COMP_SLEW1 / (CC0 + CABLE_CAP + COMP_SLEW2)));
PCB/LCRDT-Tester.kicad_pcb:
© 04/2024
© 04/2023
